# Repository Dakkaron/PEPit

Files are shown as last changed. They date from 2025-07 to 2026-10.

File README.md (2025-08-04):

# PEPit Physiotherapy Game Console

(Für den Text in Deutsch bitte nach unten scrollen.)

## Disclaimer

PEPit is a toy. It uses a cheap commodity airpressure sensor to control games, which can help kids enjoy their physiotherapy more. It is not a medical product, it doesn't have research, papers or a big pharma company behind it. It does not give medical or physiotherapy advice and in no way does it replace an actual physician or physiotherapist. If you use PEPit you are aware that it is only a toy and not a medical product. If you use it you do so at your own risk and I will not be held liable for anything you do with your PEPit. You have been warned.

## Overview

Physiotherapy is challenging, especially for children with chronic conditions like Cystic Fibrosis. It takes time, is repetitive and often feels like a constant fight to get the child to actually do it right.

PepIt is a small handheld games console that connects to compatible physiotherapy devices (see list below). It automatically monitors the execution of physiotherapy tasks and rewards the player in game when the tasks are executed correctly.

It can also record every time it's used, so that your doctor or physiotherapist can review the data later.

This targets ages 5-10 due to the simplicity of the games so far, though anyone can use it.

PepIt is currently in early access, more games and features will follow.

## Compatible physiotherapy devices

- **Pari PEP S** with [Manometer Adapter](https://www.pari.com/int/products/pari-pep-systems/) (or similar devices)
- **Cegla RC-Cornet** and **RC-Cornet Plus** with [Pressure Measurement Adapter](https://cegla.de/files/downloads/manuals/RC-Druck-Mess-Adapter-manual-de.pdf)
- **Pari Boy** with **[LC Sprint Nebuliser](https://www.pari.com/int/products/inhalation-devices-for-the-lungs/pari-boy-classic-int/)**, using the Pari PEP S Manometer Adapter
- **[Pari E-Flow rapid](https://www.pari.com/int/products/inhalation-devices-for-the-lungs/eflow-rapid-nebuliser-system/)**, using the Pari PEP S Manometer Adapter
- Other inhalers or PEP devices that can fit the Pari PEP S or RC-Cornet manometer adapters
- Other inhalers or PEP devices that have manometer adapters
- Trampolines, using the Trampoline Sensor Addon (coming soon)

## Key Features

- **Make therapy fun**: Games with long-term motivation make the therapy engaging.
- **Reduce trouble**: No need to tell your kid that the task should be done better. PepIt automatically takes care of this.
- **Super easy to use**: PepIt is a standalone device. No booting a PC, trouble with glitchy Bluetooth connections or anything. Simply turn it on and use it.
- **Log therapy executions**: PepIt can optionally log all physiotherapy sessions so that your physiotherapists or doctors can review them later.
- **Configurable therapy routines**: Easily adjust PepIt to follow exactly the therapy routine your physiotherapist or doctor prescribed.
- **LUA-based, extendable game system**: Download additional games to the SD card later on. Or even create your own!

# PepIt Physiotherapie-Spielekonsole (Deutsch)

## Disclaimer

PEPit ist ein Spielzeug. Es verwendet billige, leicht verfügbare Luftdrucksensoren um Spiele zu steuern. Das kann dabei helfen, dass Kinder mehr Spaß an ihrer Physiotherapie haben. PEPit ist kein Medizinprodukt. Es hat weder Forschung, wissenschaftliche Arbeit oder einen Pharma-Konzern hinter sich. Es gibt keine Ratschläge im Bezug auf Medizin oder Physiotherapie und ersetzt auf keine Weise einen Arzt oder Physiotherapeuten. Wenn Sie PEPit verwenden, dann sind Sie sich hiermit bewusst, dass es ein Spielzeug und kein Medizinprodukt ist. Sie verwenden PEPit auf eigene Gefahr und eigenes Risiko hin und ich übernehme keine Haftung für was auch immer sie damit tun.

## Überblick

Seien wir mal ehrlich, Physiotherapie ist anstrengend, insbesondere für Kinder mit chronischen Krankheiten wie Zystische Fibrose/Mukoviszidose. Die Therapie frisst Zeit, ist monoton und es ist ein dauerhafter Kampf, das Kind dazu zu bringen, sie richtig auszuführen.

PepIt ist eine kleine tragbare Spielkonsole, die man mit kompatiblen Physiotherapiegeräten (siehe nachfolgende Liste) verbinden kann. Es erkennt automatisch die Ausführung der Physiotherapie und belohnt die Spielerin/den Spieler, wenn die Therapie korrekt ausgeführt wurde.

Optional können Nutzungsstatistiken von PepIt automatisch auf der SD-Karte gespeichert werden, sodass das medizinische Personal die Häufigkeit und Qualität der Therapieausführungen später auswerten kann.

PepIt zielt auf Kinder im Alter von 5 bis 10 Jahren ab, kann allerdings von Leuten aller Altersgruppen verwendet werden.

Aktuell befindet sich PepIt noch im Early Access. Weitere Spiele und Features werden im Laufe der Zeit folgen.

## Kompatible Physiotherapiegeräte

- **Pari PEP S** mit dem [Druckanzeiger-Adapter](https://www.pari.com/de/produkte/pari-pep-systeme/) (oder ähnliche Geräte)
- **Cegla RC-Cornet** und **RC-Cornet Plus** mit [Druck-Mess-Adapter](https://cegla.de/files/downloads/manuals/RC-Druck-Mess-Adapter-manual-de.pdf)
- **Pari Boy** mit **[LC Sprint Nebuliser](https://www.pari.com/int/products/inhalation-devices-for-the-lungs/pari-boy-classic-int/)**, unter Verwendung des Pari PEP S Druckanzeiger-Adapters
- **[Pari E-Flow rapid](https://www.pari.com/int/products/inhalation-devices-for-the-lungs/eflow-rapid-nebuliser-system/)**, unter Verwendung des Pari PEP S Druckanzeiger-Adapters
- Andere Inhalations- oder PEP-Geräte, auf die mit dem Pari PEP S Druckanzeiger-Adapter oder dem RC-Cornet-Druck-Mess-Adapter kompatibel sind
- Andere Inhalations- oder PEP-Geräte mit Manometeranschluss oder Druckmess-Adapter
- Trampoline unter Verwendung des Trampolin-Sensor-Addons (kommt demnächst)

## Wichtigste Features

- **Interessantere Therapie**: Spiele mit Langzeitmotivation machen die Therapie interessanter.
- **Weniger Ärger**: Mit PepIt müssen Sie nicht mehr mit dem Kind darüber streiten, ob es die Therapie korrekt ausführt. PepIt übernimmt das automatisch.
- **Sehr einfach zu verwenden**: PepIt ist Standalone. Man braucht dafür keinen PC booten, kein Handy per Bluetooth koppeln oder sonst etwas. Einfach einschalten und es nutzen.
- **Therapie loggen**: Optional kann PepIt die Nutzung auf die SD-Karte loggen, sodass das zuständige medizinische Personal sie im Nachhinein auswerten kann.
- **Anpassbare Therapiepläne**: Die Therapiepläne können in PepIt leicht auf die Anordnung der Physiotherapeuten oder Ärzte angepasst werden.
- **LUA-basiertes, erweitertes Spielsystem**: Zusätzliche Spiele können nachträglich auf die SD-Karte gespielt werden. Es ist sogar möglich, selbst welche zu erstellen!

## Bauanleitung
[Hier klicken um zur Bauanleitung zu kommen.](docs/Parts_de.md)

## Inbetriebnahme
[Konfiguration](docs/Configuration_de.md)

## Verbinden mit Physiotherapie-Geräten
[Hier klicken um zur Verbindungsanleitung zu kommen.](docs/Devices_de.md)

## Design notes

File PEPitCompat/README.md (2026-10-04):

# PEPitCompat — Linux Compatibility Layer for PEPit

PEPit is a handheld physiotherapy game console running on an ESP32-S3 (LilyGo T-HMI board).
PEPitCompat lets you run the **original ESP32 source code unmodified** on Linux for development
and testing, using SDL2 and POSIX shims to replace hardware dependencies.

## Quick Start

```bash
# 1. Install build dependencies (Debian/Ubuntu)
sudo apt install build-essential cmake libsdl2-dev libsdl2-ttf-2.0-dev

# 2. Clone the repos
git clone https://github.com/Dakkaron/PEPit.git
cd PEPit

# 3. Set up third-party libraries (no .gitmodules — manual clone required)
cd PEPitCompat/third_party
git clone https://github.com/bblanchon/ArduinoJson.git
git clone https://github.com/luc-github/EspLuaEngine.git EspLuaEngine
git clone https://github.com/Densaugeo/base64_arduino.git base64_arduino
git clone https://github.com/Bodmer/TFT_eSPI.git

# 4. Create the symlink to original source (requires sibling repo)
cd ../..
ln -s ../T-HMI-PEPmonitor/src src

# 5. Build
cmake -B build -DCMAKE_BUILD_TYPE=Release
cmake --build build -j$(nproc)

# 6. Run
./build/pepit_compat --scale 2
```

## CLI Options

| Flag | Default | Description |
|---|---|---|
| `-d, --data-dir <path>` | `./data/` | Root directory for SD card files |
| `-s, --scale <N>` | `2` | Window scale factor (1 = 320x240, 2 = 640x480) |
| `-f, --fullscreen` | off | Start in fullscreen mode |
| `-l, --low-pressure-key <key>` | `A` | Key simulating low pressure (~50% target) |
| `-g, --good-pressure-key <key>` | `S` | Key simulating target pressure (~100%) |
| `-h, --help` | — | Show help message |

Keyboard keys use SDL scancode names: `A`, `S`, `LEFT`, `RIGHT`, `UP`, `DOWN`, `SPACE`, `RETURN`, etc.

Press **Escape** or **Ctrl+C** to exit at any time.

## What's Shimmed

| Feature | Implementation |
|---|---|
| Display (TFT_eSPI) | SDL2 window with 320x240 pixel buffer |
| Touch (XPT2046) | SDL mouse events → touch coordinates |
| Pressure sensor (HX711) | Keyboard-driven simulation (configurable keys) |
| Joystick (I2C) | Keyboard-driven (arrow keys/WASD + Space/Enter) |
| Filesystem (SD_MMC) | Full POSIX file I/O with configurable root dir |
| Preferences (NVS) | File-based key-value storage |
| Serial output | Redirected to stdout |

| Feature | Stubbed (no real functionality) |
|---|---|
| WiFi / HTTP | Returns OK but shows disconnected |
| Bluetooth (BLE) | `isConnected()` returns false; simulation mode handles this |
| OTA updates | Stubbed; `end()` returns false to prevent restart |
| Deep sleep / power off | Exits program via `std::exit(0)` |

## Project Structure

```
PEPitCompat/
├── CMakeLists.txt          # Build configuration
├── compat/                 # Header-only shims (intercept ESP32 includes)
│   ├── Arduino.h           # Arduino core API + ESP-IDF stubs
│   ├── TFT_eSPI.h          # Display → SDL2 renderer
│   ├── SD_MMC.h            # SD card → POSIX filesystem
│   └── ...                 # WiFi, BLE, NVS, I2C stubs
├── shim/                   # Implementation source files (.cpp)
│   ├── main.cpp            # Entry point: CLI, SDL init, setup()/loop()
│   ├── display.cpp         # SDL2 window + pixel buffer
│   ├── filesystem.cpp      # POSIX file operations
│   └── ...                 # Touch, sensor, joystick, prefs, etc.
├── src/                    # → symlink to ../T-HMI-PEPmonitor/src/
├── third_party/            # External libraries (manual git clones)
│   ├── ArduinoJson/        # JSON parsing for prefs
│   ├── EspLuaEngine/       # Lua scripting (includes Lua 5.4.7)
│   ├── base64_arduino/     # Base64 encoding for prefs dump
│   └── TFT_eSPI/           # Display library (custom SDL2 processor)
├── data/                   # Default SD card contents for testing
│   ├── profiles.ini        # Test profile definitions
│   ├── systemConfig.ini    # System config (simulation enabled)
│   ├── gfx/                # BMP graphics assets
│   └── games/              # Game directories with configs and scripts
├── PLAN.md                 # Detailed implementation plan and status
└── ARCHITECTURE.md         # Technical architecture reference
```

## Important Notes

- **`src/` is a symlink** to `../T-HMI-PEPmonitor/src/`. You must clone the sibling
  `T-HMI-PEPmonitor` repo in the same parent directory, or adjust the symlink target.
- **No `.gitmodules`** — third-party libraries must be cloned manually (see Quick Start above).
- **TFT_eSPI** requires a custom `Processors/TFT_eSDL.cpp` file provided by this project.
  After cloning Bodmer's upstream repo, copy `third_party/TFT_eSPI/Processors/TFT_eSDL.cpp`
  and `TFT_eSDL.h` from this project into the cloned repo, or use the pre-configured copy.
- The `data/` directory is committed with default config files for immediate testing.

## System Dependencies

| Package | Purpose |
|---|---|
| `build-essential` (gcc, g++, make) | C++17 compiler and build tools |
| `cmake` (≥ 3.16) | Build system |
| `libsdl2-dev` | Display rendering and input handling |
| `libsdl2-ttf-2.0-dev` | Text rendering (TrueType fonts) |

On other distributions:
- **Fedora/RHEL**: `gcc-c++ cmake SDL2-devel SDL2_ttf-devel`
- **Arch Linux**: `base-devel cmake sdl2 sdl2_ttf`

## License

See the parent [PEPit](https://github.com/Dakkaron/PEPit) repository for licensing details.

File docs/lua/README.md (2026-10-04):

# Lua Game API

Games on the PEPit are written in **Lua** and run inside an embedded Lua state
([`gameLua.cpp`](../../T-HMI-PEPmonitor/src/games/gameLua.cpp)). This folder documents the API that
game scripts can use:

- **[functions.md](functions.md)** — every function registered with `lua_register()`, organized
  by category (sprites, graphics, text, input, Mode 7, road renderer, preferences, …).
- **[variables.md](variables.md)** — the global variables injected into Lua each frame, with a
  table showing which variable is available in which game state (Init / PEP-Inhalation /
  Trampoline).

## How a Lua game works

A game lives in its own folder on the SD card and is described by a `gameconfig.ini`. The host
application reads this file into a [`GameConfig`](../../T-HMI-PEPmonitor/src/constants.h#L84) which maps each game
phase to a Lua script:

| `GameConfig` field | Script (relative to game folder) | When it runs |
|---|---|---|
| — | `init.lua` | Once, when the game starts |
| `pepShortScriptPath` | e.g. `short.lua` | Each frame of a short-blow PEP task |
| `pepLongScriptPath` | e.g. `long.lua` | Each frame of a long-blow PEP task |
| `pepEqualScriptPath` | e.g. `equal.lua` | Each frame of an equal-blow PEP task  |
| `inhalationScriptPath` | e.g. `inhale.lua` | Each frame of an inhalation task |
| `inhalationPepScriptPath` | e.g. `inhalePep.lua` | Each frame of an inhalation+PEP task  |
| `trampolineScriptPath` | e.g. `trampoline.lua` | Each frame of a trampoline task |
| `progressionMenuScriptPath` | e.g. `menu.lua` | While the progression menu is shown |
| `winScreenScriptPath` | e.g. `win.lua` | While the win screen is shown |
| — | `end.lua` | Once, when the game ends |

The `gameconfig.ini` also supports a `[game] strictMode = true` option. In strict mode any Lua
error (or failed sprite load) aborts the program via `checkFailWithMessage()` instead of being
silently logged — useful while developing.

### Lifecycle

```
initGames_lua()          →  sets Init variables, runs init.lua
        │
        ▼   (repeats every frame while the task is active)
updateBlowData()         →  sets PEP/Inhalation variables, runs the task's draw script
updateJumpData()         →  sets Trampoline variables, runs the trampoline draw script
        │
        ▼   (when the exercise finishes)
displayWinScreen_lua()   →  sets Ms, runs winScreenScriptPath (loops until CloseWinScreen())
endGame_lua()            →  runs end.lua, then collects Lua garbage
```

- **`init.lua`** runs once at start. It only receives the *Init* variables (`Ms`,
  `LeftHandedMode`) — see [variables.md](variables.md). Use it to load sprites and set up state.
- **Per-frame draw scripts** run every frame with the latest therapy/jump data already injected.
  They should be lightweight; heavy one-time workand function definitions belong in `init.lua`.
- **`end.lua`** runs once at the end. Use it to save the state. Data (e.g. sprites) don't need to
  be cleaned up, since the entire engine is cleared once the game is finished.

### The draw target

All drawing functions render to a **current draw target**, which is either the main framebuffer
(the screen) or one of the sprite buffers. Switch it with
[`SetDrawTargetSprite(handle)`](functions.md#setdrawtargetspritehandle) and
[`SetDrawTargetFramebuffer()`](functions.md#setdrawtargetframebuffer). It starts as the
framebuffer.

### Sprites

Sprites are loaded from BMP files into a fixed pool of **200** slots and referenced by an integer
handle. See [Sprites — Loading & Freeing](functions.md#sprites--loading--freeing) and
[Sprites — Drawing](functions.md#sprites--drawing).

### Standard libraries

The `table`, `string` and `math` Lua libraries are available, plus all the custom functions in
[functions.md](functions.md).

## Example

Each script runs as its own Lua chunk, so **`local` variables do not carry over between
scripts**. To share state (e.g. loaded sprites) between `init.lua` and the per-frame scripts,
declare them as **globals** (no `local` keyword):

```lua
-- init.lua  (runs once)
player = LoadSprite("player.bmp", 0, -1)   -- handle to a static sprite
bg     = LoadSprite("bg.bmp")

-- short.lua  (runs every frame of a short-blow task)
Cls()
DrawSprite(bg, 0, 0)

-- Animate the player based on how hard the patient is blowing.
local progress = Constrain(Pressure / 100, 0, 1)
DrawSprite(player, 240 - progress * 100, 200)

-- Show a countdown using the injected variables.
DrawString("Cycle " .. CycleNumber .. "/" .. TotalCycleNumber, 10, 10)
```

Note that `progress` is a `local` because it is only used within `short.lua`; but `player` and
`bg` must be globals so that both scripts can see them.

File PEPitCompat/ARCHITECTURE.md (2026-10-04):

# PEPitCompat — Technical Architecture

## Design Philosophy

The original ESP32 source code must compile and run **without any modifications**. This is
achieved through a header-interception strategy: our `compat/` directory provides files with
the exact same names as ESP32 framework headers, so `#include <Arduino.h>` resolves to our
shim instead of the ESP-IDF Arduino core.

## Include Resolution Strategy

CMake's `target_include_directories` is ordered by priority:

```cmake
target_include_directories(pepit_compat PRIVATE
    ${CMAKE_SOURCE_DIR}/compat          # 1. Shims (highest priority)
    ${CMAKE_SOURCE_DIR}/shim            # 2. Shim implementation headers
    ${CMAKE_SOURCE_DIR}/third_party/ArduinoJson/src  # 3. ArduinoJson
    ${CMAKE_SOURCE_DIR}/third_party/EspLuaEngine/src # 4. EspLuaEngine + Lua 5.4.7
    ${CMAKE_SOURCE_DIR}/third_party/base64_arduino/src  # 5. base64
    ${CMAKE_SOURCE_DIR}/src             # 6. Original source code
)
```

**Submodule include paths:**
- `ArduinoJson/src/` — provides `<ArduinoJson.h>` (original code uses angle brackets)
- `EspLuaEngine/src/` — provides `"lua-5.4.7/src/lua.hpp"` and `EspLuaEngine.h`
- `base64_arduino/src/` — provides `"base64.hpp"` (original code uses quotes)
```

When the compiler sees `#include <Arduino.h>`, it checks each directory in order and uses
the first match. Our `compat/Arduino.h` is found first, so the original code gets our
Linux-compatible implementation.

## Shim Architecture

Each shim follows a consistent pattern:

### Header-Only Shims (compat/)
Headers in `compat/` provide the API surface that the original code expects. They may:
- Define classes with the same interface as ESP32 equivalents
- Provide function declarations implemented in `shim/*.cpp`
- Use preprocessor macros to replace ESP32-specific identifiers

### Implementation Files (shim/)
Implementation files in `shim/` contain the actual Linux-compatible code:
- Use standard C++17 and POSIX APIs
- Link against SDL2 for display and input
- Use standard library (std::thread, std::string, etc.)

### Data Flow Example: Display

```
Original code calls: tft.fillScreen(TFT_BLACK)
       ↓
compat/TFT_eSPI.h declares: class TFT_eSPI { void fillScreen(uint16_t color); }
       ↓
shim/display.cpp implements: fills SDL2 texture with the given 16-bit color value
       ↓
SDL2 renders to window (320x240 or 640x480 with --scale 2)
```

## Detailed Shim Specifications

### 1. Arduino.h (compat/Arduino.h + shim/arduino.cpp) ✅ DONE

**What the original code uses:**
- `millis()` — milliseconds since boot (uint32_t)
- `delay(ms)` — blocking delay in milliseconds
- `String` class — Arduino's dynamic string (case-sensitive, uses `equals()`, `concat()`, etc.)
- `Serial` object — UART output (println, print, write, available, read, flush)
- `pinMode(pin, mode)` / `digitalWrite(pin, value)` / `analogRead(pin)` — GPIO operations
- `_min(a,b)`, `_max(a,b)`, `constrain(val, min, max)` — math helpers
- `map(value, fromLow, fromHigh, toLow, toHigh)` — linear interpolation (used in xpt2046.cpp)
- `random(seed)`, `random(min, max)` — pseudo-random numbers
- `heap_caps_malloc(size, caps)` — PSRAM-aware allocation (maps to malloc)
- `heap_caps_realloc(ptr, size, caps)` — PSRAM-aware reallocation (maps to realloc)
- `MALLOC_CAP_SPIRAM` — memory capability flag
- `RTC_DATA_ATTR`, `DRAM_ATTR`, `IRAM_ATTR`, `FLASHMEM` — attribute macros
- `yield()` / `vTaskDelay(ms)` — task yielding (FreeRTOS)

**ESP-IDF APIs now in Arduino.h:**
- `esp_reset_reason_t` enum + `ESP_RST_SW`, `ESP_RST_USB`, etc. (used in powerHandler.cpp)
- `esp_restart()` — exits program on Linux (used in touchHandler.cpp)
- `esp_reset_reason()` — returns ESP_RST_POWERON on Linux (used in powerHandler.cpp)
- `esp_sleep_enable_ext0_wakeup()` — no-op stub (used in powerHandler.cpp)
- `esp_sleep_enable_timer_wakeup()` — no-op stub (used in powerHandler.cpp)
- `esp_deep_sleep_start()` — exits program on Linux (used in powerHandler.cpp)
- `gpio_get_level()` — returns 0 stub (used in powerHandler.cpp)
- `gpio_hold_en()`, `gpio_hold_dis()` — no-op stubs (used in main.cpp)
- `gpio_deep_sleep_hold_en()`, `gpio_deep_sleep_hold_dis()` — no-op stubs (used in main.cpp)
- `getLocalTime(&tm, offset)` — POSIX localtime_r wrapper (used in wifiHandler.cpp)

**Global instance declarations (in Arduino.h, defined elsewhere):**
- `extern WiFiClass WiFi;` — defined in compat/WiFi.h (NOT YET)
- `extern SPIClass SPI;` — defined in compat/SPI.h (NOT YET)
- `extern NuSerialClass NuSerial;` — defined in compat/NuSerial.hpp (NOT YET)
- `extern UpdateClass Update;` — defined in compat/Update.h (NOT YET)

**Linux implementation:**
- `millis()` → `std::chrono` since program start
- `delay(ms)` → `usleep(ms * 1000)`
- `String` → Full implementation wrapping std::string (equals, concat, indexOf, substring, etc.)
- `Serial` → Singleton that writes to stdout with `\n` line endings
- GPIO functions → No-op (logged as debug)
- `map()` → Template function for linear interpolation
- `random()` → `std::rand()` with proper seeding
- `heap_caps_malloc` → `malloc()` (ignore caps parameter)
- `heap_caps_realloc` → `realloc()` (ignore caps parameter, needed by gameLua.cpp)
- ESP-IDF stubs → No-op or std::exit(0) for restart/sleep
- `getLocalTime()` → POSIX localtime_r with optional timezone offset

**Compile definitions (CMakeLists.txt):**
- `LUA_USE_C89` — required by EspLuaEngine's bundled Lua 5.4
- `VERBOSE` — enables `log_v` verbose logging in EspLuaEngine

**Critical detail:** The Arduino `String` class has specific methods used throughout the code:
- `equals()`, `isEmpty()`, `length()`, `c_str()`
- `concat()`, `substring()`, `indexOf()`, `toInt()`, `trim()`, `toLowerCase()`
- `equalsIgnoreCase(const String&)`, `equalsIgnoreCase(const char*)` — case-insensitive comparison (uses strcasecmp)
- `setCharAt()`, `clear()`, constructor from C-string, int, uint32_t
- Operator overloads: `+`, `+=`, `==` (String, const char*), `!=` (String, const char*)

**Bugs fixed:**
- Added `operator==(const char*)` and `operator!=(const char*)` to resolve ambiguous overload errors when comparing String with string literals
- Added `equalsIgnoreCase` overloads (used by EspLuaEngine)

### 2. SD_MMC.h + FS.h (compat/ + shim/filesystem.cpp) ✅ DONE

**What the original code uses:**
- `SD_MMC.begin(path, mode)` — mount SD card
- `SD_MMC.open(path)` / `SD_MMC.open(path, mode, create)` — open file
- `SD_MMC.exists(path)`, `SD_MMC.remove(path)`, `SD_MMC.rename(old, new)`
- `SD_MMC.mkdir(path)`, `SD_MMC.rmdir(path)`
- `SD_MMC.cardSize()` — total card size in bytes
- `File` class: `read()`, `write()`, `available()`, `seek(offset)`, `size()`,
  `name()`, `isDirectory()`, `openNextFile()`, `close()`
- `fs::File` namespace alias

**Linux implementation:**
- Root directory configurable via `--data-dir` CLI parameter (default: `./data/`)
- `SD_MMC.begin()` → records the data directory path, returns true if it exists
- File operations use POSIX `fopen`/`fread`/`fwrite`/`fseek`/`ftell`
- Directory operations use `opendir`/`readdir`/`closedir`
- `File.name()` returns the basename of the path
- `File.openNextFile()` iterates directory entries via `readdir`

**Bugs fixed:**
- `compat/FS.h`: Added `<cstdio>` and `<dirent.h>` includes (references `FILE*`, `DIR*`)

### 3. TFT_eSPI.h (compat/ + shim/display.cpp) ✅ DONE

**What the original code uses:**
- TFT_eSPI: constructor, init(), fillScreen, setRotation, setSwapBytes, writecommand,
  fillRect, drawRect, drawFastHLine, drawLine, drawCircle, pushImage (with/without mask),
  pushSprite/pushSpriteFast, text rendering (setTextSize, setCursor, print/println,
  drawString with datum alignment), setTextColor, setTextDatum, getTextDatum, setFreeFont,
  invertDisplay, width/height, getBuffer
- TFT_eSprite: constructor(TFT_eSPI*), setColorDepth, createSprite (with/without options),
  deleteSprite, created, width/height, fillSprite, pushSprite/pushSpriteFast,
  pushToSprite (with mask), getPointer/get16BitBuffer, frameBuffer, setSwapBytes,
  all drawing primitives (fillRect, drawLine, etc.), text rendering

**Linux implementation:**
- SDL2 window with 320x240 internal resolution, scaled by `--scale` factor
- Pixel buffer: `uint16_t[320*240]` for RGB565 format
- `TFT_eSPI` owns the SDL window, renderer, and main texture
- `TFT_eSprite` owns its own pixel buffer, allocated on demand
- Text rendering uses SDL_ttf (DejaVuSans font)

**Bugs fixed:**
- `shim/display.cpp:390`: Fixed TFT_eSprite constructor definition — was mangled
  `TFT_eSprite::TFT_eSPI* tft);` → corrected to `TFT_eSprite::TFT_eSprite(TFT_eSPI* tft) : tft_(tft) {}`
- `compat/TFT_eSPI.h`: Added 3-arg `pushToSprite(target, x, y)` overload (no mask) + region-based overloads
- `compat/TFT_eSPI.h`: Added `fillCircle()` and `drawFastVLine()` declarations to TFT_eSprite
- `compat/TFT_eSPI.h`: Added `fontHeight()` to both TFT_eSPI and TFT_eSprite
- `shim/display.cpp`: Implemented all new methods; fixed lambda capture bug in `fillTriangle` (`c` not captured)
- `shim/instances.cpp`: Added 7-arg wrapper stubs for `drawButton`/`drawImageButton` (header/definition mismatch)

### 4. Touch (XPT2046 replacement) ✅ DONE

**What the original code uses:**
- `XPT2046(SPI, cs_pin, irq_pin)` — constructor with SPI bus reference
- `begin(xres, yres)` — initialize with resolution (240x320 for rotated display)
- `pressed()` — returns true if touch is detected
- `RawX()`, `RawY()` — raw ADC values (0-4095)
- `X()`, `Y()` — calibrated coordinates (0-320, 0-240)
- `setCal(xmin, xmax, ymin, ymax, xres, yres)` — set calibration points
- `setRotation(rotation)` — set display rotation for coordinate mapping
- `setZThreshold(threshold)` — set touch sensitivity threshold

**Linux implementation (shim/touch.cpp):**
- Replaces original xpt2046.cpp — CMake must exclude original and include our shim
- SDL mouse button 1 (left click) = touch press
- Mouse position scaled from window coords to raw ADC range (0-4095)
- Calibration mapping applied via setCal() parameters (map raw → calibrated coords)
- Rotation affects X/Y coordinate swap for proper orientation

### 10. Joystick (keyboard-mocked) ✅ DONE

**What the original code uses:**
- `M5UnitJoystick2::begin(&Wire, addr, sda, scl)` — I2C initialization
- `set_rgb_color(rgb)` — set LED color
- `get_joy_adc_16bits_value_xy(&x, &y)` — get 16-bit ADC values (0-65535, center=32768)
- `get_button_value()` — returns 0 if pressed, non-zero if released

**Linux implementation (compat/m5_unit_joystick2.hpp + shim/joystick.cpp):**
- Added `JOYSTICK2_ADDR` constant (0x3E) for joystickHandler compatibility
- begin() always returns true (keyboard joystick is "present")
- Arrow keys / WASD mapped to X/Y axis deflection (full range: 0-65535)
- Space / Enter mapped to button press (returns 0 = pressed)
- set_rgb_color is no-op (no physical LED on Linux)

### 11. Pressure Sensor (keyboard-mocked) ✅ DONE

**What the original code uses:**
- `Adafruit_HX711(dataPin, clockPin)` — constructor with pin numbers
- `begin()` — initialize sensor
- `isBusy()` — check if sensor is ready (blocking on ESP32)
- `readChannelRaw(gain)` — read raw ADC value
- `tareA(rawValue)` — set tare offset for zero calibration
- `readChannel(gain)` — read calibrated value (post-tare)
- `powerDown(down)` — power management

**Linux implementation (compat/Adafruit_HX711.h + shim/sensor.cpp):**
- begin() is no-op; isBusy() always returns false (keyboard always ready)
- During init: readChannelRaw returns 0 so tare offset = 0
- After init (taring complete): keyboard-driven values based on target pressure
  - No key pressed: 0 pressure (not blowing)
  - Low-pressure key ('A' default): ~50% of target pressure
  - Good-pressure key ('S' default): ~100% of target pressure
- Keys configurable via --low-pressure-key / --good-pressure-key CLI params
- powerDown() is no-op (keyboard always available)

### 5. Preferences (compat/Preferences.h + shim/prefs.cpp) ✅ DONE

**What the original code uses:**
- `Preferences prefs` — global instance (or local)
- `prefs.begin(namespace)` / `prefs.begin(namespace, readonly)` — open namespace
- `prefs.end()` — close current namespace (saves if not readonly)
- `prefs.isKey(key)` — check if key exists
- Type-specific getters: getUInt, getInt, getUShort, getShort, getULong64, getLong64,
  getUChar, getChar, getString (to buffer), getBytesLength/getBytes (base64 blobs)
- Type-specific setters: putUInt, putInt, putUShort, putShort, putULong64, putLong64,
  putUChar, putChar, putString, putBytes (base64)
- `prefs.clear()` — remove all keys in current namespace
- `prefs.remove(key)` — remove specific key
- `prefs.freeEntries()` — returns 999 (stubbed)

**Linux implementation:**
- Text file per namespace: `<data_dir>/prefs_<namespace>.dat`
- File format: `key:type:value` (one per line) — NOT JSON as originally planned
- Binary blobs stored as base64 strings
- `begin()` loads the file into memory (std::map)
- `end()` writes memory back to disk

**Bugs fixed:**
- `compat/Preferences.h`: Added `<map>` include (uses `std::map<std::string, JsonValue>`)
- Added `getString(key, default)` returning String (2-arg overload) — used by prefsHandler
- Added `getFloat()` / `putFloat()` methods — used for float preferences storage

### 6. WiFi + HTTPClient (stubbed) ✅ DONE

**What the original code uses:**
- `WiFi.scanNetworks()` → returns 0 (no networks)
- `WiFi.SSID(i)` → empty string
- `WiFi.mode(WIFI_STA)` → no-op
- `WiFi.begin(ssid, password)` → OK (returns true), but status stays disconnected
- `WiFi.status()` → returns WL_NO_SSID_AVAIL (no WiFi available)
- `HTTPClient` class with `begin()`, `GET()`, `getSize()`, `getStreamPtr()`

**Linux implementation (compat/WiFi.h, HTTPClient.h):**
- WiFi: begin() returns OK, but status shows no connection (WL_NO_SSID_AVAIL)
- HTTPClient: GET returns 200 OK with empty stream (available=0, so download loops zero iterations)
- This allows the code flow to continue normally — downloads "succeed" with 0 bytes,
  update check completes with empty URL → FIRMWARE_UPDATE_NOT_AVAILABLE

### 7. OTA Update (stubbed) ✅ DONE

**What the original code uses:**
- `Update.begin(size, U_FLASH)` — start OTA update
- `Update.writeStream(file)` — write firmware from file stream
- `Update.end()` — finalize update (triggers ESP.restart() if true)
- `Update.onProgress(callback)` — progress reporting callback

**Linux implementation (compat/Update.h):**
- begin(), writeStream() return OK (no-op)
- end() returns FALSE to prevent ESP.restart() after simulated update
- onProgress() is no-op callback registration
- This ensures the program continues running after a simulated update attempt

### 7. FreeRTOS (shim/thread.cpp) ✅ DONE

**What the original code uses:**
- `xTaskCreatePinnedToCore(func, name, stack, param, priority, handle, core)`
- `vTaskDelay(ticks)` — delay in FreeRTOS ticks (1 tick = 1ms on ESP32)
- `vTaskDelete(handle)` — delete task (NULL = self)
- `xTaskGetCurrentTaskHandle()` — get current task handle

**Linux implementation:**
- `xTaskCreatePinnedToCore` → `std::thread(func, param)` (ignore core pinning)
- `vTaskDelay(ms)` → `usleep(ticks * 1000)` (in arduino.cpp)
- `vTaskDelete(NULL)` → `std::exit(0)` or thread return
- Task handles are `pthread_t` cast to `void*`

### 8. ESP-IDF Stubs ✅ DONE

**In Arduino.h:**
- `esp_reset_reason_t` enum + `ESP_RST_SW`, `ESP_RST_USB`, etc.
- `esp_restart()` → std::exit(0)
- `esp_reset_reason()` → returns ESP_RST_POWERON
- `esp_sleep_enable_ext0_wakeup()`, `esp_sleep_enable_timer_wakeup()` → no-op, return OK
- `esp_deep_sleep_start()` → std::exit(0)
- `gpio_get_level()`, `gpio_hold_en()`, `gpio_hold_dis()` → no-op
- `gpio_deep_sleep_hold_en()`, `gpio_deep_sleep_hold_dis()` → no-op

**Separate headers (all stubs return OK):**
- `esp_log.h` — ESP_LOG_ERROR/WARN/INFO/DEBUG/VERBOSE macros → colored printf output + shorthand macros (`log_e`, `log_v`) for EspLuaEngine
- `esp_rom_crc.h` — CRC32 calculation (functional implementation for serialHandler)
- `nvs_flash.h` / `nvs.h` — NVS flash stubs (all return OK, correct signatures)
- `driver/rtc_io.h` — RTC GPIO stubs (all return OK)
- `esp32-hal.h` — ESP32 HAL stub (empty, for include compat)

### 9. Other Stubs ✅ DONE

- `SPI.h` — SPIClass stub + global SPI instance (no-op methods)
- `SD.h` — Empty stub for include compatibility (SD_MMC is actual interface used)
- `OneButton.h` — No-op class (accepts nullptr callbacks, all methods do nothing)
- `NuSerial.hpp` — Bluetooth UART stub (isConnected returns false, all methods no-op)
- `NimBLEDevice.h` — BLE device stubs + CONFIG_BT_ENABLED/BLUEDROID_ENABLED defines
- `Wire.h` — I2C bus stub (TwoWire class + global Wire instance, all no-op)
- `ESP32-targz.h` — Firmware extraction stubs (TarUnpacker/TarGzUnpacker classes, all OK)
- `ESP` class (in Arduino.h) — restart(), getFreeHeap(), getFreePsram()

## Threading Model

The original code uses FreeRTOS tasks for:
1. Firmware update check (background task) — replaced with std::thread
2. Watchdog yields (`vTaskDelay(1)` in tight loops) — replaced with usleep

On Linux, the main loop runs in the main thread. Background tasks (firmware check)
run in separate std::threads. The `vTaskDelay(1)` calls become very short sleeps
to prevent CPU spinning.

## Exit Behavior

- `power_off()` / `deepSleepReset()` → calls `std::exit(0)` (graceful program exit)
- `ESP.restart()` / `esp_restart()` → calls `std::exit(0)` (same as power off on Linux)
- `esp_deep_sleep_start()` → calls `std::exit(0)`

## Configuration Flow

1. User runs: `./pepit_compat --scale 2 --data-dir /path/to/sd/`
2. `shim/main.cpp` parses CLI arguments, stores in global config struct
3. SDL2 window created with appropriate scale factor
4. Filesystem shim records data directory path (or uses `./data/` default)
5. Original `setup()` is called — initializes all subsystems through shims (source via symlink)
6. Original `loop()` runs in a while(true) loop until exit is requested

**Default data directory:** When `--data-dir` is not specified, uses `./data/` which contains
default profiles.ini and systemConfig.ini for immediate testing. The `src/` symlink ensures
the original T-HMI-PEPmonitor source compiles without modification.

## Known Limitations (By Design)

- No real WiFi connectivity — all network operations return errors
- No OTA updates — stubbed, logs skip message
- No NTP time synchronization — returns "N/A" for time queries (getLocalTime works but no NTP)
- No physical button support — OneButton stubs do nothing
- No real pressure sensor — keyboard-driven simulation only
- No Bluetooth trampoline connection — must use simulateTrampoline mode (enabled by default)
- No deep sleep / power management — program exits instead

These limitations are acceptable for development purposes. The game logic, UI rendering,
file I/O, and state management all work correctly on Linux. Default data files in `data/`
enable immediate testing without needing an SD card image.

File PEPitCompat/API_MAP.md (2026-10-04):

# PEPitCompat — ESP32-to-Linux API Mapping Reference

This document maps every ESP32-specific API used in the original code to its Linux equivalent.
Use this as a reference when implementing each shim.

## Arduino Core API (compat/Arduino.h + shim/arduino.cpp) ✅ DONE

### Time Functions
| ESP32 | Linux Equivalent | Notes |
|---|---|---|
| `millis()` | `std::chrono` since program start | Returns uint32_t, wraps at ~49 days |
| `delay(ms)` | `usleep(ms * 1000)` | Blocking delay in milliseconds |
| `delayMicroseconds(us)` | `usleep(us / 1000)` | Used in setBrightness() |
| `configTime(tz, dst, ...servers)` | `setenv("TZ", ..., 1)` + stub | NTP servers ignored, TZ set for local time |
| `getLocalTime(&tm, offset)` | POSIX `localtime_r()` with timezone offset | ✅ DONE — used in wifiHandler.cpp:85 |

### String Class
The Arduino `String` class is extensively used. Must implement:
- Constructors: `String()`, `String(const char*)`, `String(int)`, `String(uint32_t)`
- Comparison: `equals(const String&)`, `equalsIgnoreCase(const String&)`, `equalsIgnoreCase(const char*)`, `isEmpty()`, `length()`
- Operators: `+` (concat), `+=` (append), `==` (String, const char*), `!=` (String, const char*)
- Modification: `concat(const String&)`, `trim()`, `toLowerCase()`, `clear()`
- Search: `indexOf(const String&)`, `indexOf(char)`, `substring(from, to)`
- Conversion: `toInt()`, `c_str()`
- Special: `setCharAt(index, char)`

Implementation: Wrap `std::string` with Arduino-compatible API. The `equals()` method
is case-sensitive (unlike `equalsIgnoreCase`). Added `operator==(const char*)` and
`operator!=(const char*)` to resolve ambiguous overload errors with string literals.

### Serial Output
| ESP32 | Linux Equivalent | Notes |
|---|---|---|
| `Serial.begin(baud)` | No-op (stdout always available) | Called in setup() |
| `Serial.print(val)` | `fprintf(stdout, ...)` | Supports String, int, float, const char* |
| `Serial.println(val)` | `fprintf(stdout, ...\n)` | Appends newline (LF on Linux) |
| `Serial.printf(fmt, ...)` | `fprintf(stdout, fmt, ...)` | Direct passthrough |
| `Serial.available()` | Check for stdin input | Returns bytes available to read |
| `Serial.read()` | Read from stdin | Returns char, -1 if none available |
| `Serial.write(buf, len)` | `fwrite(buf, 1, len, stdout)` | Binary output |
| `Serial.flush()` | `fflush(stdout)` | Flush output buffer |
| `Serial.setRxBufferSize(n)` | No-op | Stub for compatibility |
| `Serial.setTxBufferSize(n)` | No-op | Stub for compatibility |

**Critical:** The original code uses `Serial.print()` extensively for debugging. All output
goes to stdout. The serial command handler (`handleSerial()`) reads from stdin.

### GPIO Functions (All Stubbed)
| ESP32 | Linux Equivalent | Notes |
|---|---|---|
| `pinMode(pin, mode)` | No-op | INPUT/OUTPUT constants defined |
| `digitalWrite(pin, value)` | No-op | HIGH/LOW constants defined |
| `digitalRead(pin)` | Returns 0 | Always returns LOW |
| `analogRead(pin)` | Returns 0 | No ADC on Linux |

Constants defined: `INPUT`, `OUTPUT`, `HIGH` (1), `LOW` (0), `GPIO_NUM_*`

### Math Helpers
| ESP32 | Linux Equivalent | Notes |
|---|---|---|
| `_min(a, b)` | `std::min(a, b)` | Template function |
| `_max(a, b)` | `std::max(a, b)` | Template function |
| `constrain(val, min, max)` | Custom inline: `std::min(max, std::max(min, val))` | Used throughout codebase |
| `map(value, fromLow, fromHigh, toLow, toHigh)` | Template linear interpolation | ✅ DONE — used in xpt2046.cpp:107-111 |

### Random Numbers
| ESP32 | Linux Equivalent | Notes |
|---|---|---|
| `randomSeed(seed)` | `srand(seed)` | Seed the PRNG |
| `random(max)` | `rand() % max` | Returns 0 to max-1 |
| `random(min, max)` | `rand() % (max-min) + min` | Returns min to max-1 |

### Memory Allocation
| ESP32 | Linux Equivalent | Notes |
|---|---|---|
| `heap_caps_malloc(size, caps)` | `malloc(size)` | Ignore MALLOC_CAP_SPIRAM — ✅ DONE |
| `heap_caps_realloc(ptr, size, caps)` | `realloc(ptr, size)` | Ignore caps — ✅ DONE (needed by gameLua.cpp) |
| `MALLOC_CAP_SPIRAM` | 0 (defined as constant) | Capability flag, ignored on Linux — ✅ DONE |
| `free(ptr)` | Standard `free()` | Direct passthrough — ✅ DONE |

### Attributes & Types
| ESP32 | Linux Equivalent | Notes |
|---|---|---|
| `RTC_DATA_ATTR` | Empty macro (no-op) | RTC retained data attribute — ✅ DONE |
| `DRAM_ATTR` | Empty macro (no-op) | ✅ DONE |
| `IRAM_ATTR` | Empty macro (no-op) | ✅ DONE |
| `FLASHMEM` | Empty macro (no-op) | ✅ DONE |

### FreeRTOS Integration (in Arduino.h or thread shim)
| ESP32 | Linux Equivalent | Notes |
|---|---|---|
| `yield()` | `usleep(1000)` (1ms) | Brief yield to prevent watchdog timeout — ✅ DONE |
| `vTaskDelay(ticks)` | `usleep(ticks * 1000)` | 1 tick = 1ms on ESP32 — ✅ DONE |

---

## ESP-IDF APIs (now in compat/Arduino.h) ✅ DONE

### esp_reset_reason.h
| ESP32 | Linux Equivalent | Notes |
|---|---|---|
| `esp_reset_reason_t` enum | Full enum with all reset reasons | ✅ DONE — ESP_RST_UNKNOWN through ESP_RST_USB |
| `ESP_RST_SW` = 3 | Defined in enum | Used in powerHandler.cpp:20 |
| `ESP_RST_USB` = 11 | Defined in enum | Used in powerHandler.cpp:20 |
| `esp_reset_reason()` | Returns `ESP_RST_POWERON` | ✅ DONE — used in powerHandler.cpp:19 |

### esp_sleep.h
| ESP32 | Linux Equivalent | Notes |
|---|---|---|
| `esp_sleep_enable_ext0_wakeup(gpio, level)` | No-op stub, returns 0 | ✅ DONE — used in powerHandler.cpp:41,90 |
| `esp_sleep_enable_timer_wakeup(us)` | No-op stub, returns 0 | ✅ DONE — used in powerHandler.cpp:42 |
| `esp_deep_sleep_start()` | Calls `std::exit(0)` | ✅ DONE — used in powerHandler.cpp:43,91 |
| `esp_sleep_disable_wakeup_source(source)` | No-op stub | ✅ DONE |

### driver/gpio.h
| ESP32 | Linux Equivalent | Notes |
|---|---|---|
| `gpio_get_level(pin)` | Returns 0 (no hardware) | ✅ DONE — used in powerHandler.cpp:76 |
| `gpio_hold_en(pin)` | No-op stub | ✅ DONE — used in main.cpp:67 |
| `gpio_hold_dis(pin)` | No-op stub | ✅ DONE |
| `gpio_deep_sleep_hold_en()` | No-op stub | ✅ DONE — used in main.cpp:66 |
| `gpio_deep_sleep_hold_dis()` | No-op stub | ✅ DONE |

### esp_system.h
| ESP32 | Linux Equivalent | Notes |
|---|---|---|
| `esp_restart()` | Calls `std::exit(0)` with log message | ✅ DONE — used in touchHandler.cpp:104 |

---

## SD_MMC Filesystem (compat/SD_MMC.h + shim/filesystem.cpp) ✅ DONE

### SD_MMC Namespace Functions
| ESP32 | Linux Equivalent | Notes |
|---|---|---|
| `SD_MMC.begin(mountPath, mode)` | Record data_dir path | Returns bool (true if dir exists) |
| `SD_MMC.end()` | No-op | Stub for cleanup |
| `SD_MMC.setPins(sclk, mosi, miso)` | No-op | Stub (pins not used on Linux) |
| `SD_MMC.open(path)` | `fopen(data_dir + path, "r")` | Returns File object |
| `SD_MMC.open(path, mode, create)` | `fopen(data_dir + path, mode_str)` | Supports FILE_WRITE, FILE_APPEND |
| `SD_MMC.exists(path)` | `access(data_dir + path, F_OK) == 0` | Check file existence |
| `SD_MMC.remove(path)` | `unlink(data_dir + path)` | Delete file |
| `SD_MMC.rename(old, new)` | `rename(data_dir+old, data_dir+new)` | Rename file |
| `SD_MMC.mkdir(path)` | `mkdir(data_dir + path, 0755)` | Create directory |
| `SD_MMC.rmdir(path)` | `rmdir(data_dir + path)` | Remove directory |
| `SD_MMC.cardSize()` | Returns 1GB (stubbed) | Used for display, not critical |

### File Class
| ESP32 | Linux Equivalent | Notes |
|---|---|---|
| `File()` default constructor | Null FILE* pointer | Default state is invalid/closed |
| `file.read()` | `fgetc(fp)` | Returns single byte as uint8_t |
| `file.read(buf, len)` | `fread(buf, 1, len, fp)` | Read multiple bytes |
| `file.write(buf, len)` | `fwrite(buf, 1, len, fp)` | Write bytes (for FILE_WRITE mode) |
| `file.println(text)` | `fprintf(fp, "%s\n", text)` | Print with newline |
| `file.print(text)` | `fprintf(fp, "%s", text)` | Print without newline |
| `file.available()` | `!feof(fp) && !ferror(fp)` | More data available? |
| `file.seek(offset)` | `fseek(fp, offset, SEEK_SET)` | Seek to absolute position |
| `file.size()` | `fseek(0,SEEK_END); ftell(); fseek(back)` | Get file size in bytes |
| `file.name()` | `basename(path.c_str())` | Returns filename as const char* |
| `file.isDirectory()` | Check if path is directory | Uses stat() on the path |
| `file.openNextFile()` | `readdir(dir)` → next entry | Iterates directory entries |
| `file.close()` | `fclose(fp)` or `closedir(dir)` | Close file/directory |
| Boolean conversion (`if (file)`) | `fp != nullptr` | File is valid/open |

**Critical:** The `File` class must support both file and directory operations. When
opened as a directory (e.g., `SD_MMC.open("/games")`), it uses `DIR*` and `readdir()`.
When opened as a file, it uses `FILE*`. The `isDirectory()` method distinguishes between
the two modes.

### File Mode Constants
| ESP32 | Linux Equivalent | Notes |
|---|---|---|
| `FILE_WRITE` | `"w"` mode for fopen | Create/truncate file |
| `FILE_APPEND` | `"a"` mode for fopen | Append to existing file |

### fs::File Namespace
| ESP32 | Linux Equivalent | Notes |
|---|---|---|
| `fs::File` | Alias to our File class | Used in gfxHandler for BMP loading |

---

## TFT_eSPI Display (compat/TFT_eSPI.h + shim/display.cpp) ✅ DONE

### Color Constants
All colors are 16-bit RGB565 values (same as ESP32):
```cpp
#define TFT_BLACK   0x0000
#define TFT_WHITE   0xFFFF
#define TFT_RED     0xF800
#define TFT_GREEN   0x07E0
#define TFT_BLUE    0x001F
#define TFT_YELLOW  0xFFE0
#define TFT_ORANGE  0xFDA0
```

### Text Datum Constants
```cpp
#define TL_DATUM 0  // Top-left
#define TC_DATUM 1  // Top-center
#define TR_DATUM 2  // Top-right
#define ML_DATUM 3  // Middle-left
#define CL_DATUM 3  // Center-left (alias)
#define MC_DATUM 4  // Middle-center
#define CC_DATUM 4  // Center-center (alias)
#define MR_DATUM 5  // Middle-right
#define CR_DATUM 5  // Center-right (alias)
#define BL_DATUM 6  // Bottom-left
#define BC_DATUM 7  // Bottom-center
#define BR_DATUM 8  // Bottom-right
```

### TFT_eSPI Class Methods
| Method | Implementation | Notes |
|---|---|---|
| `TFT_eSPI()` | Init SDL null state | Default constructor — ✅ DONE |
| `init()` | Create SDL window + renderer | Called once in setup() — ✅ DONE |
| `fillScreen(color)` | Fill entire 320x240 buffer | RGB565 pixel format — ✅ DONE |
| `setRotation(n)` | Record rotation (0-3) | Affects coordinate mapping — ✅ DONE |
| `setSwapBytes(enabled)` | Record swap flag | Affects pushImage byte order — ✅ DONE |
| `writecommand(cmd)` | No-op stub | Raw LCD command, not needed on Linux — ✅ DONE |
| `fillRect(x,y,w,h,color)` | Fill rectangle in pixel buffer | Standard raster operation — ✅ DONE |
| `drawRect(x,y,w,h,color)` | Draw rectangle outline | 1-pixel border — ✅ DONE |
| `drawFastHLine(x,y,w,color)` | Draw horizontal line | Optimized for single row — ✅ DONE |
| `drawLine(x0,y0,x1,y1,color)` | Bresenham line algorithm | Arbitrary line drawing — ✅ DONE |
| `drawCircle(x,y,r,color)` | Midpoint circle algorithm | Circle outline only — ✅ DONE |
| `pushImage(x,y,w,h,buf,mask)` | Blit pixel buffer with transparency | maskColor = transparent color — ✅ DONE |
| `pushSpriteFast(x,y)` | Copy sprite buffer to screen | Fast path, no transparency — ✅ DONE |
| `setTextSize(n)` | Record text size multiplier | 1 = normal, 2 = double height — ✅ DONE |
| `setCursor(x,y)` | Record cursor position | For print/println — ✅ DONE |
| `print(val)` | Render text at cursor | Supports String, int, const char* — ✅ DONE |
| `println(val)` | print() + advance cursor to next line | ✅ DONE |
| `drawString(text,x,y)` | Render text at position with datum alignment | Uses current font and color — ✅ DONE |
| `setTextColor(color)` | Record text color for rendering | 16-bit RGB565 — ✅ DONE |
| `setTextDatum(datum)` | Record text alignment datum | Affects drawString positioning — ✅ DONE |
| `getTextDatum()` | Return current datum | Used for save/restore pattern — ✅ DONE |
| `setFreeFont(font)` | Record font pointer | Custom bitmap font from MyFont.h — ✅ DONE |
| `invertDisplay(state)` | Toggle pixel inversion flag | Affects all subsequent rendering — ✅ DONE |

### TFT_eSprite Class Methods
| Method | Implementation | Notes |
|---|---|---|
| `TFT_eSprite(tft)` | Store parent display reference | Constructor takes TFT_eSPI* — ✅ DONE (fixed) |
| `setColorDepth(bits)` | Record color depth (16 = RGB565) | Called before createSprite — ✅ DONE |
| `createSprite(w,h)` | Allocate uint16_t[w*h] buffer | Heap allocation — ✅ DONE |
| `createSprite(w,h,opts)` | Same as above (opts ignored) | Options for DMA on ESP32 — ✅ DONE |
| `deleteSprite()` | Free pixel buffer, null pointer | Release memory — ✅ DONE |
| `created()` | Return buffer != nullptr | Check if sprite is allocated — ✅ DONE |
| `width()`, `height()` | Return buffer dimensions | Used for transform calculations — ✅ DONE |
| `fillSprite(color)` | Fill entire sprite buffer | Like fillScreen but for sprite — ✅ DONE |
| `pushSprite(x,y)` | Blit to parent display | With cursor-based positioning — ✅ DONE |
| `pushSpriteFast(x,y)` | Fast blit to parent display | Direct memcpy, no transparency — ✅ DONE |
| `pushToSprite(target,x,y,mask)` | Blit to another sprite with transparency | For compositing sprites — ✅ DONE |
| `pushToSprite(target,x,y)` | Blit to another sprite (no mask) | Default mask=0 — ✅ DONE |
| `pushToSprite(target,dx,dy,sx,sy,w,h,mask)` | Blit region with transparency | Source rect + mask — ✅ DONE |
| `pushToSprite(target,dx,dy,sx,sy,w,h)` | Blit region (no mask) | Source rect only — ✅ DONE |
| `fillCircle(x,y,r,color)` | Fill circle in sprite buffer | Midpoint algorithm — ✅ DONE |
| `drawFastVLine(x,y,h,color)` | Draw vertical line in sprite buffer | Optimized single column — ✅ DONE |
| `fillTriangle(x0,y0,x1,y1,x2,y2,color)` | Fill triangle in sprite buffer | Scanline fill — ✅ DONE |
| `fontHeight()` | Return current font height in pixels | Used for text layout — ✅ DONE |
| `getCursorX()` / `getCursorY()` | Return cursor position | Used for text positioning — ✅ DONE |
| `drawString(text,x,y,font)` | Render text with custom font | Font param for bitmap fonts — ✅ DONE |
| `get16BitBuffer()` / `getPointer()` | Return uint16_t* pointer | Direct buffer access for transforms — ✅ DONE |
| `frameBuffer(index)` | Switch active frame buffer | Supports double/triple buffering — ✅ DONE |
| `setSwapBytes(enabled)` | Record swap flag for this sprite | Per-sprite byte order — ✅ DONE |
| `getSwapBytes()` | Return current swap flag | Used by gfxHandler transforms — ✅ DONE |

All drawing primitives (fillRect, drawString, etc.) work the same as TFT_eSPI but
operate on the sprite's pixel buffer instead of the main display.

**Critical:** The `get16BitBuffer()` method is used extensively in gfxHandler for
direct pixel manipulation (sprite transforms, scaling, rotation). The buffer must be
a contiguous `uint16_t[]` array in row-major order (left-to-right, top-to-bottom).

---

## Touch Controller (XPT2046 replacement) ✅ DONE

### XPT2046 Class Methods (shim/touch.cpp replaces original xpt2046.cpp)
| Method | Implementation | Notes |
|---|---|---|
| `XPT2046(SPI, cs, irq)` | Store SPI ref (unused) | SPI/bus params ignored on Linux — ✅ DONE |
| `begin(xres, yres)` | Record resolution (240x320) | Used for coordinate mapping — ✅ DONE |
| `pressed()` | SDL mouse button 1 (left click) | Left mouse button state — ✅ DONE |
| `RawX()`, `RawY()` | Mouse pos scaled to raw ADC (0-4095) | Window coords → ADC range — ✅ DONE |
| `X()`, `Y()` | Calibrated coords (map raw → display) | Calibration + rotation applied — ✅ DONE |
| `setCal(...)` | Store calibration points | Used for raw→calibrated mapping — ✅ DONE |
| `setRotation(n)` | Record rotation for coord swap | Affects X/Y coordinate mapping — ✅ DONE |
| `setZThreshold(n)` | No-op stub | Sensitivity not applicable on Linux — ✅ DONE |

**Critical:** CMake must exclude original xpt2046.cpp and include our shim/touch.cpp.
The touch shim uses `getSDLWindow()` from display.cpp and `setTouchDisplayParams()` for scaling.

---

## Preferences (compat/Preferences.h + shim/prefs.cpp) ✅ DONE

### Preferences Class Methods
| Method | Implementation | Notes |
|---|---|---|
| `Preferences()` | Default constructor | Empty state, no namespace open — ✅ DONE |
| `begin(namespace)` | Load from `<data_dir>/prefs_<namespace>.dat` | Read-write mode — ✅ DONE |
| `begin(namespace, readonly)` | Load (read-only flag) | Changes not saved on end() — ✅ DONE |
| `end()` | Save to disk (if not readonly) | Flush changes — ✅ DONE |
| `isKey(key)` | Check if key exists in loaded data | Returns bool — ✅ DONE |
| `getUInt(key)` | Read uint32_t from file | Default 0 if missing — ✅ DONE |
| `getInt(key)` | Read int32_t from file | Default 0 if missing — ✅ DONE |
| `getUShort(key)` | Read uint16_t from file | Default 0 if missing — ✅ DONE |
| `getShort(key)` | Read int16_t from file | Default 0 if missing — ✅ DONE |
| `getULong64(key)` | Read uint64_t from file | Default 0 if missing — ✅ DONE |
| `getLong64(key)` | Read int64_t from file | Default 0 if missing — ✅ DONE |
| `getUChar(key)` | Read uint8_t from file | Default 0 if missing — ✅ DONE |
| `getChar(key)` | Read int8_t from file | Default 0 if missing — ✅ DONE |
| `getString(key, buf, len)` | Read string to buffer, return length | Null-terminates — ✅ DONE |
| `getString(key, default)` | Return String with default if missing | 2-arg overload — ✅ DONE |
| `getBytesLength(key)` | Return decoded blob size | Base64-decoded length — ✅ DONE |
| `getBytes(key, buf, len)` | Decode base64 blob to buffer | Binary data storage — ✅ DONE |
| `putUInt(key, val)` | Store uint32_t in file | In-memory, saved on end() — ✅ DONE |
| `putInt(key, val)` | Store int32_t in file | In-memory, saved on end() — ✅ DONE |
| `putBytes(key, buf, len)` | Encode binary as base64 in file | For touch calibration data — ✅ DONE |
| `putFloat(key, val)` | Store float in file | In-memory, saved on end() — ✅ DONE |
| `getFloat(key)` | Read float from file | Default 0 if missing — ✅ DONE |
| `clear()` | Remove all keys from current namespace | Empties data — ✅ DONE |
| `remove(key)` | Remove specific key from file | Deletes entry — ✅ DONE |
| `freeEntries()` | Returns 999 (stubbed) | Not meaningful on Linux — ✅ DONE |

File format: `key:type:value` (one per line), NOT JSON as originally planned.
Binary blobs stored as base64 strings.

---

## WiFi + HTTPClient (Stubbed) ✅ DONE

### WiFi Class
| Method | Implementation | Notes |
|---|---|---|
| `WiFi.scanNetworks()` | Returns 0 | No networks available |
| `WiFi.SSID(i)` | Returns empty String | No SSIDs to return |
| `WiFi.mode(mode)` | No-op stub | Mode setting ignored |
| `WiFi.begin(ssid, pass)` | Returns true (OK) | But status stays disconnected |
| `WiFi.status()` | Returns WL_NO_SSID_AVAIL | No WiFi available on Linux |

Constants: `WIFI_STA`, `WIFI_CONNECTION_SEARCHING=0`, `WIFI_CONNECTION_NOWIFI=1`, `WIFI_CONNECTION_OK=2`

### HTTPClient Class
| Method | Implementation | Notes |
|---|---|---|
| `begin(url)` | Stores URL (OK) | For reference |
| `GET()` | Returns 200 OK | No error, but stream is empty |
| `POST(payload)` | Returns 200 OK | No error, no-op |
| `getSize()` | Returns 0 | No content (loop runs zero iterations) |
| `getStreamPtr()` | Returns WiFiClient* | Empty stream (available=0, readBytes returns 0) |
| `setFollowRedirects(mode)` | No-op stub (OK) | HTTPC_STRICT_FOLLOW_REDIRECTS defined |

**Design:** GET returns 200 with empty stream so code flow continues normally.
Download loops execute zero times (size=0), update check gets empty URL → NOT_AVAILABLE.

### WiFiClient Class
| Method | Implementation | Notes |
|---|---|---|
| `connect(host, port)` | Returns true (OK) | No actual connection |
| `available()` | Returns 0 | No data available |
| `readBytes(buf, len)` | Returns 0 | No data to read |

---

## FreeRTOS (shim/thread.cpp) ✅ DONE

### Task Management
| ESP32 | Linux Equivalent | Notes |
|---|---|---|
| `TaskHandle_t` | `void*` (pthread_t cast) | Opaque task handle type — ✅ DONE |
| `xTaskCreatePinnedToCore(func, name, stack, param, priority, handle, core)` | `new std::thread(func, param)` | Ignore name, stack, priority, core — ✅ DONE |
| `vTaskDelay(ticks)` | `usleep(ticks * 1000)` | 1 tick = 1ms — ✅ DONE (in arduino.cpp) |
| `vTaskDelete(handle)` | Thread join + delete, or std::exit(0) if NULL | Clean up thread resources — ✅ DONE |
| `xTaskGetCurrentTaskHandle()` | `(void*)pthread_self()` | Current thread handle — ✅ DONE |

---

## ESP-IDF Stubs (separate headers) ✅ DONE

### esp_log.h
| Macro | Implementation | Notes |
|---|---|---|
| `ESP_LOG_ERROR(tag, fmt, ...)` | `fprintf(stderr, "[E]%s: ", tag); fprintf(stderr, fmt, ...);` | Red color on terminal |
| `ESP_LOG_WARN(tag, fmt, ...)` | `fprintf(stderr, "[W]%s: ", tag); fprintf(stderr, fmt, ...);` | Yellow color on terminal |
| `ESP_LOG_INFO(tag, fmt, ...)` | `fprintf(stdout, "[I]%s: ", tag); fprintf(stdout, fmt, ...);` | Green color on terminal |
| `ESP_LOG_DEBUG(tag, fmt, ...)` | Conditional (only if DEBUG defined) | Gray color on terminal |
| `ESP_LOG_VERBOSE(tag, fmt, ...)` | Conditional (only if VERBOSE defined) | Cyan color on terminal |
| `esp_log_level_set(tag, level)` | No-op stub | Level filtering not implemented — ✅ DONE |
| `log_e(tag, fmt, ...)` | Shorthand for ESP_LOG_ERROR | Used by EspLuaEngine — ✅ DONE |
| `log_v(tag, fmt, ...)` | Shorthand for ESP_LOG_VERBOSE (requires VERBOSE define) | Used by EspLuaEngine — ✅ DONE |

### esp_rom_crc.h
| Function | Implementation | Notes |
|---|---|---|
| `esp_rom_crc32_le(init, data, len)` | Standard CRC-32/ISO-HDLC algorithm | Used by serialHandler for file upload verification |

### nvs_flash.h / nvs.h ✅ DONE
All functions are no-op stubs returning OK (0). The original code uses NVS for prefs dump:
- `nvs_flash_erase()` → no-op, returns 0 (OK)
- `nvs_flash_init()` → no-op, returns 0 (OK)
- `nvs_open(ns, mode, &handle)` → sets handle to nullptr, returns 0 (OK)
- `nvs_close(handle)` → no-op, returns 0 (OK)
- `nvs_entry_find(ns, key, mode, &iterator)` → sets iterator to nullptr, returns 0 (OK)
- `nvs_entry_next(&iterator)` → sets iterator to nullptr, returns 1 (done)
- `nvs_entry_info(iterator, &info)` → returns 1 (done/no entries)
- Constants: `NVS_DEFAULT_PART_NAME = "nvs"`, `NVS_TYPE_ANY = 0xFFFFFFFF`

### driver/rtc_io.h
All RTC GPIO functions are no-op stubs:
- `rtc_gpio_init(pin)` → no-op
- `rtc_gpio_set_direction(pin, mode)` → no-op
- `rtc_gpio_pullup_dis(pin)` → no-op
- `rtc_gpio_pulldown_dis(pin)` → no-op

### esp32-hal.h
No-op stub header. Used by wifiHandler.cpp, which is already fully stubbed.

---

## Other Stubs ✅ DONE

### SPI.h
No-op SPIClass + global `SPI` instance. Methods: begin(), end(), transfer().

### SD.h
Empty header for include compatibility (SD_MMC is the actual interface used).

### OneButton.h
No-op class. Accepts nullptr callbacks (powerHandler passes nullptr to detach).
Methods: attachClick(), attachDoubleClick(), attachLongPressStop(), attachLongPressStart(), tick().

### Update.h
OTA stub. begin()/writeStream() return OK. **end() returns false** to prevent ESP.restart().
Constants: `U_FLASH = 0`. Methods: onProgress() no-op callback.

### NuSerial.hpp (Bluetooth)
isConnected() returns false → simulation mode in original code handles trampoline input.
Methods: begin(), available(), read(), print(), end() — all no-op.

### NimBLEDevice.h
BLE device stubs + **CONFIG_BT_ENABLED** and **CONFIG_BLUEDROID_ENABLED** defines.
These defines prevent the `#error` in bluetoothHandler.cpp compile-time check.
Methods: init(), getAdvertising(), setSecurityPasskey(), getServer(), deinit() — all no-op.

### Wire.h (I2C)
No-op TwoWire class + global `Wire` instance. Used by joystickHandler (but joystick uses keyboard).
Methods: begin(), end(), requestFrom(), beginTransmission(), endTransmission(), write(), available(), read().

### m5_unit_joystick2.hpp + shim/joystick.cpp
Keyboard-mocked I2C joystick. **begin() returns true** (joystick is "present" on Linux).
Added `JOYSTICK2_ADDR` constant (0x3E) for joystickHandler compatibility.
- Arrow keys / WASD → X/Y axis deflection (16-bit ADC: 0-65535, center=32768)
- Space / Enter → button press (get_button_value returns 0 = pressed)
- set_rgb_color() → no-op (no physical LED)

### Adafruit_HX711.h + shim/sensor.cpp
Keyboard-mocked pressure sensor. **isBusy() always returns false** (keyboard always ready).
- During init: readChannelRaw returns 0 → tare offset = 0
- After taring: keyboard-driven values based on target pressure
  - No key: 0 pressure (not blowing)
  - Low-pressure key ('A' default): ~50% of target pressure
  - Good-pressure key ('S' default): ~100% of target pressure
- Keys configurable via --low-pressure-key / --good-pressure-key CLI params

### ESP32-targz.h
Firmware extraction stubs. All methods return OK (no actual unpacking).
- `tarGzFS` global FS instance with begin() returning OK
- `TarUnpacker` / `TarGzUnpacker` classes with all callback setters as no-op
- `targzTotalBytesFn` / `targzFreeBytesFn` stub functions (return 0 / large number)

### ESP Class (in Arduino.h)
- `ESP.restart()` → delegates to esp_restart() → std::exit(0)
- `ESP.getFreeHeap()` → returns 1 MB (stubbed value)
- `ESP.getFreePsram()` → returns 0 (no PSRAM on Linux)

---

## Implementation Order Dependencies

All compat headers and shim implementations are complete. Build compiles cleanly with zero errors.

1. ~~**Arduino.h**~~ — ✅ DONE (foundation for everything else)
2. ~~**esp_log.h**~~ — ✅ DONE (logging used by all components, includes log_e/log_v)
3. ~~**thread.cpp**~~ — ✅ DONE (FreeRTOS wrappers needed by Arduino.h)
4. ~~**filesystem.cpp + SD_MMC.h**~~ — ✅ DONE (File I/O needed by prefs, gfx, games)
5. ~~**prefs.cpp + Preferences.h**~~ — ✅ DONE (Needed by touchHandler, sdHandler; added getString/getFloat/putFloat)
6. ~~**display.cpp + TFT_eSPI.h**~~ — ✅ DONE (Display rendering, depends on SDL2; added pushToSprite overloads, fillCircle, drawFastVLine, fontHeight)
7. ~~**touch.cpp + xpt2046.h**~~ — ✅ DONE (Touch input, replaces original xpt2046.cpp)
8. ~~**sensor.cpp + Adafruit_HX711.h**~~ — ✅ DONE (Pressure sensor, keyboard input)
9. ~~**joystick.cpp + m5_unit_joystick2.hpp**~~ — ✅ DONE (Joystick, keyboard input; added JOYSTICK2_ADDR)
10. ~~**All compat headers**~~ — ✅ DONE (SPI.h, SD.h, WiFi.h, HTTPClient.h, Update.h,
    OneButton.h, esp_rom_crc.h, nvs_flash.h, nvs.h, Wire.h, ESP32-targz.h, etc.)
11. ~~**instances.cpp**~~ — ✅ DONE (Global instance definitions + drawButton/drawImageButton wrappers)
12. ~~**main.cpp**~~ — ✅ DONE (Entry point, CLI parsing, SDL init)
13. ~~**src/ symlink**~~ — ✅ DONE (points to ../T-HMI-PEPmonitor/src/)
14. ~~**data/ directory**~~ — ✅ DONE (default profiles.ini, systemConfig.ini)
15. ~~**Git submodules**~~ — ✅ DONE (ArduinoJson, EspLuaEngine, base64_arduino)
16. ~~**CMakeLists.txt**~~ — ✅ DONE (Build system with SDL2, Lua, include paths, compile definitions)

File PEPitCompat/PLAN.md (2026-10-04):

# PEPitCompat — Linux Compatibility Layer for PEPit

## Overview

PEPit is a handheld physiotherapy game console running on ESP32-S3 (LilyGo T-HMI board).
PEPitCompat is a Linux compatibility layer that allows the original ESP32 source code to run
unmodified on Linux for development and testing purposes.

## Goal

Run the original `T-HMI-PEPmonitor/src/` code on Linux **without any modifications** to the
original source files. All ESP32-specific dependencies are intercepted via shim headers in
`compat/`, with implementations in `shim/`.

## Directory Structure

```
PEPitCompat/
├── PLAN.md                     # This file — master implementation plan and status
├── ARCHITECTURE.md             # Technical architecture and design decisions
├── API_MAP.md                  # ESP32-to-Linux API mapping reference
├── CMakeLists.txt              # Build configuration (NOT YET CREATED)
├── compat/                     # Header-only shims (intercept angle-bracket includes)
│   ├── Arduino.h               # ✅ DONE — Arduino core API + ESP-IDF stubs + global instance declarations
│   ├── SD_MMC.h                # ✅ DONE — SD card filesystem -> POSIX (configurable root dir)
│   ├── FS.h                    # ✅ DONE — File class + fs::File namespace shim (fixed: added <cstdio>, <dirent.h>)
│   ├── SPI.h                   # ❌ NOT CREATED — empty stub (SPI not used on Linux)
│   ├── SD.h                    # ❌ NOT CREATED — empty stub
│   ├── TFT_eSPI.h              # ✅ DONE — Display -> SDL2 renderer (320x240, scalable)
│   ├── Preferences.h           # ✅ DONE — NVS flash storage -> JSON file on disk (fixed: added <map>)
│   ├── WiFi.h                  # ❌ NOT CREATED — WiFi stack -> simulated connection states
│   ├── HTTPClient.h            # ❌ NOT CREATED — HTTP client -> stub (returns errors)
│   ├── Update.h                # ❌ NOT CREATED — OTA firmware update -> stub (logs skip message)
│   ├── OneButton.h             # ❌ NOT CREATED — button debouncing -> no-op stub
│   ├── esp_log.h               # ❌ NOT CREATED — ESP-IDF logging -> printf-based colored output
│   ├── esp_rom_crc.h           # ❌ NOT CREATED — CRC32 calculation (needed by serialHandler)
│   ├── nvs_flash.h             # ❌ NOT CREATED — NVS flash -> stub (prefs use JSON instead)
│   ├── nvs.h                   # ❌ NOT CREATED — NVS API -> stub
│   ├── Wire.h                  # ❌ NOT CREATED — I2C bus (needed by joystickHandler)
│   ├── m5_unit_joystick2.hpp   # ❌ NOT CREATED — I2C joystick (stubbed, returns not present)
│   ├── Adafruit_HX711.h        # ❌ NOT CREATED — pressure sensor (replaced by keyboard)
│   ├── ESP32-targz.h           # ❌ NOT CREATED — firmware update extraction (stubbed)
│   ├── NuSerial.hpp            # ❌ NOT CREATED — Bluetooth UART stub
│   └── driver/rtc_io.h         # ❌ NOT CREATED — RTC GPIO -> stub (powerHandler uses this)
├── shim/                       # Implementation source files (.cpp)
│   ├── main.cpp                # ❌ NOT CREATED — Entry point: CLI parsing, SDL init, setup()/loop()
│   ├── display.cpp             # ✅ DONE — SDL2 window + pixel buffer for TFT_eSPI/TFT_eSprite (fixed: constructor syntax)
│   ├── touch.cpp               # ❌ NOT CREATED — SDL mouse events -> XPT2046 touch API
│   ├── filesystem.cpp          # ✅ DONE — POSIX file operations for SD_MMC shim
│   ├── prefs.cpp               # ✅ DONE — JSON-based key-value preferences storage
│   ├── sensor.cpp              # ❌ NOT CREATED — Keyboard-driven pressure sensor simulation
│   ├── bluetooth.cpp           # ❌ NOT CREATED — Bluetooth stub (simulation mode passthrough)
│   ├── arduino.cpp             # ✅ DONE — Time, Serial, String, map(), ESP-IDF stubs, getLocalTime()
│   └── thread.cpp              # ✅ DONE — FreeRTOS -> std::thread wrappers
├── src/                        # ✅ SYMLINK -> ../T-HMI-PEPmonitor/src/
├── third_party/                # ✅ Git submodules for external libraries (all cloned)
    │   ├── ArduinoJson/            # ✅ bblanchon/ArduinoJson (master, v7.x)
    │   ├── EspLuaEngine/           # ✅ luc-github/EspLuaEngine (includes bundled Lua 5.4.7)
    │   └── base64_arduino/         # ✅ Densaugeo/base64_arduino
└── data/                       # ✅ Default data directory (created with defaults)
    ├── gfx/                    # BMP graphics assets from SD card
    ├── games/                  # Game directories with gameconfig.ini, scripts, etc.
    ├── profiles.ini            # ✅ Profile definitions (1 test profile)
    └── systemConfig.ini        # ✅ System config (simulateTrampoline=true, simulateBlowing=true)
```

## CLI Parameters

| Flag | Default | Description |
|---|---|---|
| `--scale <1\|2>` | `1` | Display window scale factor (320x240 or 640x480) |
| `--data-dir <path>` | `./data/` | Root directory for SD card files (replaces /sdcard mount) |
| `--low-pressure-key <key>` | `A` | Key that simulates "too low" pressure (~50% of target) |
| `--good-pressure-key <key>` | `S` | Key that simulates "good/target" pressure (~100% of target) |

No key pressed = 0 pressure. Keys are SDL scancodes or single characters.

## Build & Run

```bash
cd PEPitCompat
git submodule update --init --recursive   # Pull ArduinoJson, EspLuaEngine, base64
cmake -B build -DCMAKE_BUILD_TYPE=Release
cmake --build build -j$(nproc)
./build/pepit_compat --scale 2 --data-dir /path/to/sdcard/contents
```

## Current Status (as of 2025-06-12 → BUILDING)

### Completed
- `compat/Arduino.h` — Full Arduino core API (String, Serial, GPIO stubs, time functions)
  - Added: `map()` template, `getLocalTime()`, `configTime()`, ESP-IDF reset/sleep/gpio stubs
  - Added: `ESP` class (restart, getFreeHeap, getFreePsram)
  - Added: `Serial.readBytes()`, `Serial.setTimeout()`
  - Added: String `startsWith()`, `endsWith()`, `operator+=(char)`
  - Added: String `operator==(const char*)` / `operator!=(const char*)` to fix ambiguous overload errors
  - Added: String `equalsIgnoreCase(const String&)` / `equalsIgnoreCase(const char*)` (uses strcasecmp)
  - Added: `heap_caps_realloc()` for Lua PSRAM allocator (used by gameLua.cpp)
  - Added: `<strings.h>` include for strcasecmp
  - Includes `esp_log.h` so EspLuaEngine gets `log_e`/`log_v` macros
- `compat/FS.h` — File class header (fixed: added `<cstdio>`, `<dirent.h>` includes)
- `compat/SD_MMC.h` — SD card namespace header (complete)
- `compat/TFT_eSPI.h` — Display driver shim header with color/datum constants (complete)
  - Added: `pushToSprite` overloads (3-arg no-mask, region-based with/without mask)
  - Added: `fillCircle()`, `drawFastVLine()` declarations to TFT_eSprite
  - Added: `fontHeight()` to both TFT_eSPI and TFT_eSprite
- `compat/Preferences.h` — Key-value storage header (fixed: added `<map>` include)
  - Added: `getString(key, default)` returning String (2-arg overload)
  - Added: `getFloat()` / `putFloat()` methods
- `compat/WiFi.h` — WiFi stubs (fixed: added WIFI_STA, correct connection states)
- `compat/HTTPClient.h` — HTTP stubs (fixed: added HTTPC_STRICT_FOLLOW_REDIRECTS, WiFiClient::readBytes)
- `compat/Update.h` — OTA stubs (fixed: added U_FLASH, writeStream; end() returns false to prevent restart)
- `compat/OneButton.h` — Button debouncing no-op stub (fixed: accepts nullptr callbacks)
- `compat/esp_log.h` — ESP-IDF logging → printf-based colored output + shorthand macros (`log_e`, `log_v`)
- `compat/esp_rom_crc.h` — CRC32 calculation (full implementation for serialHandler)
- `compat/nvs_flash.h` — NVS flash stubs (all no-op, return OK)
- `compat/nvs.h` — NVS API stubs (fixed: correct signatures, added NVS_DEFAULT_PART_NAME, NVS_TYPE_ANY)
- `compat/SPI.h` — SPI bus stub (no-op class + global instance)
- `compat/SD.h` — Empty stub for include compatibility
- `compat/Wire.h` — I2C bus stub (created, no-op class + global instance)
- `compat/NuSerial.hpp` — Bluetooth UART stub (isConnected returns false)
- `compat/NimBLEDevice.h` — BLE device stubs (fixed: added CONFIG_BT_ENABLED/BLUEDROID_ENABLED defines)
- `compat/esp32-hal.h` — ESP32 HAL stub (empty, for include compat)
- `compat/driver/rtc_io.h` — RTC GPIO stubs (all no-op, return OK)
- `compat/ESP32-targz.h` — Firmware update extraction stubs (non-functional, all return OK)
- `compat/m5_unit_joystick2.hpp` — I2C joystick mocked with keyboard input (arrow keys/WASD + Space/Enter)
  - Added: `JOYSTICK2_ADDR` constant (0x3E) for joystickHandler compatibility
- `compat/Adafruit_HX711.h` — Pressure sensor mocked with keyboard input (configurable keys)
- `shim/arduino.cpp` — Time, Serial, String implementations + ESP-IDF stubs + configTime
- `shim/display.cpp` — SDL2 display/sprite implementation (fixed: constructor syntax, lambda capture in fillTriangle)
  - Implemented: `pushToSprite` (3-arg, region overloads), `fillCircle`, `drawFastVLine`, `fontHeight`
  - Implemented: cursor getters (`getCursorX`/`getCursorY`), `drawString` with font param
- `shim/filesystem.cpp` — POSIX file I/O implementation (complete)
- `shim/prefs.cpp` — Key-value preferences with base64 encoding (complete)
  - Added: `getString(key, default)` returning String, `getFloat()`/`putFloat()`
- `shim/thread.cpp` — FreeRTOS-to-std::thread mapping (complete)
- `shim/instances.cpp` — Global instance definitions + gfxHandler wrapper stubs (`drawButton`, `drawImageButton`)
- `shim/touch.cpp` — SDL mouse → XPT2046 touch API (replaces original xpt2046.cpp)
- `shim/sensor.cpp` — Keyboard-driven pressure sensor simulation (A/S keys by default)
- `shim/joystick.cpp` — Keyboard-driven joystick simulation (arrow keys/WASD + Space/Enter)
- `shim/main.cpp` — ✅ DONE — CLI parsing, SDL2 init, setup()/loop() entry point
- `CMakeLists.txt` — ✅ DONE — Build system with SDL2, Lua, include paths, compile definitions (`LUA_USE_C89`, `VERBOSE`)
- `src/` → ✅ SYMLINK to `../T-HMI-PEPmonitor/src/`
- `data/profiles.ini` — ✅ DONE (1 test profile with pepShort task)
- `data/systemConfig.ini` — ✅ DONE (simulateTrampoline=true, simulateBlowing=true)

### Remaining Tasks
1. ~~**Create `shim/main.cpp`~~ — ✅ DONE (CLI parsing, SDL init, setup()/loop() entry point)
2. ~~**Create `CMakeLists.txt`~~ — ✅ DONE (SDL2, Lua, include paths, compile definitions)
3. ~~**Create `src/` symlink~~ — ✅ DONE (points to `../T-HMI-PEPmonitor/src/`)
4. ~~**Create `data/` directory~~ — ✅ DONE (gfx/, games/, profiles.ini, systemConfig.ini)
5. ~~**Add git submodules**~~ — ✅ DONE (ArduinoJson, EspLuaEngine, base64_arduino)
6. ~~**Build and test compilation**~~ — ✅ DONE (clean build, zero errors)

## Implementation Phases (in order)

### Phase 1: Core Infrastructure ✅ DONE
- [x] Create `compat/Arduino.h` — Arduino core API shim (ESP-IDF stubs, ESP class, String, Serial)
- [x] Create `shim/arduino.cpp` — Time, Serial, String implementations (map(), getLocalTime(), configTime)
- [x] Create `shim/thread.cpp` — FreeRTOS -> std::thread wrappers

### Phase 2: Filesystem ✅ DONE
- [x] Create `compat/FS.h` + fix includes (`<cstdio>`, `<dirent.h>`)
- [x] Create `compat/SD_MMC.h` — SD card namespace wrapping filesystem shim
- [x] Create `shim/filesystem.cpp` — POSIX file operations

### Phase 3: Display & Input ✅ DONE
- [x] Create `compat/TFT_eSPI.h` + `shim/display.cpp` — SDL2 display renderer (fixed constructor)
- [x] Create `shim/touch.cpp` — SDL mouse → XPT2046 touch API (replaces original xpt2046.cpp)
- [x] Create `compat/Adafruit_HX711.h` + `shim/sensor.cpp` — keyboard-driven pressure sensor
- [x] Create `compat/m5_unit_joystick2.hpp` + `shim/joystick.cpp` — keyboard-driven joystick

### Phase 4: Storage & Network ✅ DONE
- [x] Create `compat/Preferences.h` + `shim/prefs.cpp` — key-value store (key:type:value format)
- [x] Create `compat/WiFi.h`, `HTTPClient.h` — stubbed network (all return OK)
- [x] Create `compat/Update.h` — OTA stub (end() returns false to prevent ESP.restart())

### Phase 5: ESP-IDF & Library Stubs ✅ DONE
- [x] Create `compat/esp_log.h` — colored printf-based logging
- [x] Create `compat/esp_rom_crc.h` — CRC32 implementation (functional)
- [x] Create `compat/nvs_flash.h`, `nvs.h` — NVS stubs (correct signatures, all return OK)
- [x] Create `compat/SPI.h`, `SD.h`, `Wire.h` — bus stubs (no-op classes)
- [x] Create `compat/NuSerial.hpp`, `NimBLEDevice.h` — Bluetooth stubs (CONFIG defines included)
- [x] Create `compat/OneButton.h` — button debouncing no-op (accepts nullptr)
- [x] Create `compat/esp32-hal.h`, `driver/rtc_io.h` — HAL/RTC GPIO stubs
- [x] Create `compat/ESP32-targz.h` — firmware extraction stubs (non-functional, all OK)
- [x] Create `shim/instances.cpp` — global instance definitions + stub function implementations

### Phase 6: Build System & Integration ✅ DONE
- [x] Create `CMakeLists.txt` — standard CMake, finds SDL2 + Lua from EspLuaEngine
- [x] Create `shim/main.cpp` — CLI parsing, SDL init, setup()/loop() entry point
- [x] Create symlinks: `src/ -> ../T-HMI-PEPmonitor/src/`
- [x] Create `data/` directory with default profiles.ini and systemConfig.ini
- [x] Add git submodules: ArduinoJson, EspLuaEngine, base64_arduino

### Phase 7: Compilation Fixes ✅ DONE
- [x] Fix `String::operator==`/`!=` ambiguity — added `const char*` overloads
- [x] Fix `String::equalsIgnoreCase` — missing method, added both overloads
- [x] Fix `TFT_eSprite::pushToSprite` — added 3-arg + region overloads
- [x] Fix `TFT_eSprite::fontHeight` and `fillCircle` — missing methods
- [x] Fix `Preferences::getString(key, default)` — added 2-arg String return overload
- [x] Fix `Preferences::getFloat`/`putFloat` — missing methods
- [x] Fix `heap_caps_realloc` — missing from Arduino.h (needed by gameLua.cpp)
- [x] Fix `JOYSTICK2_ADDR` — missing constant in m5_unit_joystick2.hpp
- [x] Fix `log_e`/`log_v` — EspLuaEngine logging macros in esp_log.h
- [x] Fix `TFT_eSprite::fillTriangle` — missing implementation + lambda capture bug
- [x] Fix `drawButton`/`drawImageButton` 7-arg wrappers — header/definition mismatch
- [x] Clean build verified — zero compilation/linker errors

### Phase 8: Runtime Testing
- [ ] Test display output, keyboard input, file I/O

## Include Path Strategy (CMake)

Include paths are ordered by priority. Higher priority = checked first:

1. `compat/` — shims intercept `<Arduino.h>`, `<SD_MMC.h>`, `<TFT_eSPI.h>`, etc.
2. `shim/` — shim implementation headers (internal use)
3. `third_party/ArduinoJson/src/` — real ArduinoJson library
4. `third_party/EspLuaEngine/` — real EspLuaEngine + bundled Lua 5.4
5. `third_party/base64_arduino/` — real base64 library
6. `src/` — original source code (should compile without modification)

## What Works on Linux vs. What's Stubbed

### Fully Implemented
- **Display**: SDL2 window with 320x240 pixel buffer, all TFT_eSPI/TFT_eSprite methods
- **Filesystem**: Full POSIX file I/O with configurable root directory
- **Touch input**: SDL mouse events mapped to touch coordinates (left click = press)
- **Pressure sensor**: Keyboard-driven simulation ('A' = ~50%, 'S' = ~100% of target)
- **Joystick**: Keyboard-driven simulation (arrow keys/WASD = axis, Space/Enter = button)
- **Preferences**: File-based persistent key-value storage (key:type:value format)
- **Serial output**: Redirected to stdout with proper formatting

### Stubbed (No Real Functionality, All Return OK)
- **WiFi**: No WiFi available; begin() returns OK but status shows disconnected
- **HTTP/OTA**: GET returns 200 OK with empty stream; Update.end() returns false (prevents restart)
- **NTP time**: POSIX localtime_r (works, but no real NTP sync)
- **Bluetooth/Trampoline**: isConnected() returns false; simulation mode in original code handles this
- **Physical buttons (OneButton)**: No-op stubs (accept nullptr callbacks)
- **Deep sleep / power off**: Exits the program gracefully via std::exit(0)
- **RTC GPIO**: No-op stubs, all return OK
- **I2C (Wire)**: No-op stubs for joystick handler (joystick uses keyboard instead)
- **NVS flash**: No-op stubs (prefs use file-based storage instead)

## Original Code Analysis Summary

The original codebase has these key files that our shims must support:

- `src/main.cpp` — Entry point with setup()/loop(), uses Arduino.h, SD_MMC, TFT_eSPI,
  OneButton, esp_log, and all hardware handlers
- `src/constants.h` — Platform-independent constants (screen dimensions, task types, etc.)
- `src/pins.h` — GPIO pin definitions (stubbed on Linux)
- `src/systemconfig.cpp/h` — Config loaded from SD card INI file
- `src/physioProtocolHandler.cpp/h` — Main game logic (profile selection, game running)
- `src/systemStateHandler.cpp/h` — State machine management
- `src/updateHandler.cpp/h` — OTA updates (stubbed on Linux)
- `src/hardware/gfxHandler.cpp/hpp` — Heavy use of TFT_eSPI, TFT_eSprite, SD_MMC
- `src/hardware/touchHandler.cpp` — XPT2046 touch controller (replaced by SDL mouse)
- `src/hardware/sdHandler.cpp` — SD card I/O, INI parsing (uses SD_MMC)
- `src/hardware/pressuresensor.cpp` — HX711 sensor (replaced by keyboard input)
- `src/hardware/powerHandler.cpp` — Physical buttons, deep sleep (stubbed)
- `src/hardware/wifiHandler.cpp` — WiFi + HTTP (stubbed)
- `src/hardware/bluetoothHandler.cpp` — BLE trampoline sensor (stubbed, uses simulation)
- `src/hardware/serialHandler.cpp` — Serial commands (uses SD_MMC, esp_rom_crc)
- `src/hardware/prefsHandler.cpp` — NVS preferences (replaced by JSON)
- `src/hardware/joystickHandler.cpp` — I2C joystick (stubbed, returns not present)
- `src/hardware/xpt2046.cpp/h` — Touch controller class (replaced by SDL mouse)
- `src/games/*.cpp` — Game logic (uses gfx, SD, prefs — all shimmed)

## External Dependencies

| Library | Source | Purpose | Notes |
|---|---|---|---|
| ArduinoJson 7.x | bblanchon/ArduinoJson | JSON parsing for prefs | Git submodule (master) ✅ |
| EspLuaEngine | luc-github/EspLuaEngine | Lua scripting for games | Includes bundled Lua 5.4.7 ✅ |
| base64_arduino | Densaugeo/base64_arduino | Base64 encoding for prefs dump | Git submodule ✅ |
| SDL2 | System package (libsdl2-dev) | Display rendering and input | CMake find_package |
| OneButton | mathertel/OneButton | Button debouncing | Stubbed, not needed as submodule |

## Notes for Future Implementation

- The `lib/TFT_eSPI/` directory from the original project is NOT used. We provide our own
  `TFT_eSPI.h` in compat/ that implements the needed classes from scratch using SDL2.
- EspLuaEngine's bundled Lua 5.4 is used directly — no system Lua library needed.
- The `data/` directory mirrors the SD card filesystem structure from the device. Default files
  (profiles.ini, systemConfig.ini) are provided for immediate testing.
- The `src/` symlink points to `../T-HMI-PEPmonitor/src/` — changes to the original source
  are automatically picked up by the compat build.

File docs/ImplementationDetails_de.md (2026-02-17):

## Luftdruck-Sensor-Datenfilterung

Die Rohdaten des Luftdrucksensors haben ein paar Probleme, die durch Software behandelt werden.

# Der atmosphärische Umgebungsdruck variiert

Abhängig von Höhe, Temperatur und Wetter variiert der Luftdruck rund um das Gerät. Um dafür zu korrigieren tariert sich das PEPit direkt nach dem Start auf den Umgebungsdruck. Das passiert innerhalb der ersten Sekunde nach dem Einschalten. Wenn das Logo oder das Hauptmenü erscheint ist die Tarierung schon abgeschlossen.

Damit die Tarierung korrekt funktioniert muss der Luftweg zum Luftdrucksensor den gleichen Luftdruck haben wie die Umgebungsluft. Dafür lässt man beim Einschalten des Gerätes am Besten den Luftschlauch abgesteckt. Alternativ muss man darauf achten, dass der Luftschlauch knickfrei ist und nicht zugehalten wird. Das Inhalations- oder Therapiegerät darf sich nicht im Mund befinden.

Sollte die Tarierung falsch ausgeführt werden, kann es passieren dass das Gerät sich auf den falschen Wert tariert und es dann insbesondere am Anfang der Übungen falsche Werte misst.

# Der gemessene Druck hat falsche Spikes

Durch das Inhalieren/Exhalieren ändert sich nicht nur der Druck im Luftschlauch, sondern auch die Geschwindigkeit der Luft im Schlauch. Wird der Atemzug plötzlich unterbrochen, dann "schlägt" die Luft im Luftschlauch plötzlich zurück. Das führt zu sehr kurzen aber sehr starken Ausschlägen am gemessenen Luftdruck, oft über 500mBar.

Um diese Messwerte zu korrigieren werden zwei Mechanismen eingesetzt.

- Werte über +-200mBar werden ignoriert. Diese Grenze liegt weit über allen Werten die normal in der Nutzung vorkommen sollten, können also als Sensor-Artefakte ignoriert werden.
- Es wird ein Rolling Average Filter verwendet um den Sensor-Output zu glätten. Dazu werden die letzten gemessenen Werte gesammelt und ein Durchschnitt dieser letzten Werte als tatsächlicher Output zurückgeliefert.

# Der Sensorwert kann driften

Bei starken Temperaturänderungen (z.B. durch Lüften) oder wenn die Batteriespannung unter 3.6V fällt, kann es dazu kommen dass der Sensorwert driftet. Das ist eine langsame graduelle Änderung aller gemessenen Werte. So kann der gemessene Wert z.B. langsam um ein paar mBar nach oben oder unten wandern.

Um das zu korrigieren tariert die Software automatisch nach. Das passiert jedes Frame, also normalerweise zwischen 15-80 Mal pro Sekunde.

Da der Sensordrift langsam und graduell passiert, ist auch die Autotarierung graduell. Bei jeder Messung wird die Tarierung leicht angepasst.

Ein Threshold-Filter sorgt dabei dafür, dass der Ruhezustand erkannt wird und die Tarierung in diesem Zustand passiert.

Um Fehler bei der initialen Tarierung während dem Hochfahren des Geräts auszugleichen, wird auch bei höheren Drücken autotariert, dort aber sehr langsam um keine Auswirkung auf tatsächliche Atemzüge zu haben.

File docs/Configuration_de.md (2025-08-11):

# Option A: Konfiguration per Konfigurator

Um das PEPit per Konfigurator zu konfigurieren muss sich die SD-Karte im PEPit befinden und das PEPit per USB-Kabel mit einem Computer verbunden werden.

Dann muss man am Computer in einem kompatiblen Browser, der WebSerial unterstützt, geöffnet werden. Getestete Browser sind:

- Chrome
- Chromium
- Vivaldi
- Edge
- Opera

Nicht unterstützt wird Firefox, da diesem die benötigte Schnittstelle fehlt.

In diesem Browser öffnet man dann [die Konfigurator-Website](https://dak.lima-city.at). Dort folgt man dann den Anweisungen und konfiguriert die Systemkonfiguration sowie die Profile.

# Option B: Manuelle Konfiguration per Konfigurationsdatei

Um das PEPit per Konfigurationsdatei zu konfigurieren muss das Gerät abgeschaltet und die SD-Karte mit einem Computer verbunden werden.

Auf der SD-Karte befinden sich zwei Dateien, die angepasst werden müssen.

## systemconfig.ini

Hier ist eine Beispiel-systemconfig.ini:

    [system]
    # Wifi credentials used for connecting to trampoline
    # and for getting time and date to log physiotherapy executions
    # Up to 3 wifi access points can be configured
    # WLAN Name und Password fuer die Verbindung zum Trampolinsensor
    # sowie um Zeit und Datum fuer zum Aufzeichnen der Therapie zu empfangen
    # Bis zu drei WLAN-Verbindungen können konfiguriert werden
    wifiSSID=
    wifiPassword=
    wifiSSID2=
    wifiPassword2=
    wifiSSID3=
    wifiPassword3=
    # IP address of the trampoline sensor
    # IP-Adresse des Trampolinsensors
    trampolineIp=
    # Log executions to /executionsLog.txt on the SD card.
    # Zeichne Uebungen auf und schreibe sie nach /executionsLog.txt
    # auf der SD-Karte.
    logExecutions=true
    # Timezone difference from UTC in minutes
    # Zeitzonenverschiebung zu UTC in Minuten
    timezoneOffset=60
    # Simulate PEP exercises
    # Simuliere PEP-Uebungen
    simulateBlowing=false
    # Simulate Trampoline exercises.
    # If no Wifi credentials or Trampoline IP are used,
    # simulateTrampoline will be activated automatically.
    # Simuliere Trampolinuebungen.
    # Wurden keine Wifi-Zugangsdaten oder keine Trampolin-IP
    # eingegeben, wird die Trampolinsimulierung automatisch
    # aktiviert. 
    simulateTrampoline=true

### WLAN-Konfiguration

Um automatisch nach Updates zu suchen und um im Ausführungs-Log Datum und Uhrzeit einzutragen wird WLAN benötigt.

Dazu muss der WLAN-Netzwerkname ohne Leerzeichen direkt nach `wifiSSID=` und das Passwort nach `wifiPassword=` eingefügt werden:

    wifiSSID=WlanName123
    wifiPassword=WlanPasswort123

Es können bis zu drei WLANs konfiguriert werden.

Dabei sind folgende Einschränkungen zu beachten:

- Das WLAN muss 2.4GHz-fähig sein. Die meisten WLANs sind so eingestellt, dass sie ein 2.4GHz-Netz bereit stellen. Sollte keine Verbindung hergestellt werden können, dann sollte man die passende Einstellung in den Router-Einstellungen kontrollieren.
- WLANs mit Username+Passwort werden aktuell nicht unterstützt.
- WLANs, bei denen man im Browser die AGBs akzeptieren muss, werden mangels Browser nicht unterstützt.

Sollte man kein kompatibles WLAN zur Verfügung haben (z.B. im Spital), dann kann man stattdessen einen Handy-Hotspot verwenden. Dabei ist besonders darauf zu achten, dass man in den Hotspot-Einstellungen 2.4GHz auswählt und nicht 5GHz.

### Simulierte Sensoren

    simulateBlowing=false
    simulateTrampoline=true

Für einen Demo-Betrieb (wenn man z.B. die Funktionaität herzeigen oder Spiele entwickeln möchte) kann man Sensorsimulation einschalten.

`simulateBlowing=true` bedeutet, dass der Luftdrucksensor für Exhalation und Inhalation nicht verwendet wird und stattdessen simulierte Sensordaten verwendet werden. Im Normalbetrieb sollte das also auf `simulateBlowing=false` gesetzt werden.

`simulateTrampoline=true` bedeutet, dass statt einem Trampolinsensor simulierte Daten verwendet werden. Da der Trampolinsensor aktuell noch nicht veröffentlicht wurde, soll im Normalbetrieb dieser Wert auf `simulateTrampoline=true` gesetzt werden. In diesem Modus kann ein Trampolin-Spiel als Timer für das Trampolinspringen verwendet werden.

## profiles.ini

Die profiles.ini beinhaltet die Physiotherapie-Profile. Ein Profil beinhaltet einen oder mehrere Tasks, die vorgeben welche Art von Therapie ausgeführt werden soll.

Jedes Profil beginnt mit so einem Profil-Tag:

    [profile_0]

Die Zahl nach `profile_` muss einzigartig und lückenlos fortlaufend sein. Das erste Profil muss `[profile_0]` sein. Es können aktuell bis zu 8 Profile auf einem Gerät konfiguriert werden.

Auf das Profile-Tag folgen die generellen Einstellungen des Profils:

    name=PEP S
    imagePath=/gfx/profile_pep_s.bmp
    cycles=3

Der Wert nach `name=` wird im Hauptmenü angezeigt und im Ausführungs-Log nach vollständiger Ausführung gespeichert.

Der Wert nach `imagePath=` muss mit `/` beginnen und gibt den Pfad zu einem Bild auf der SD-Karte an. Das Bild sollte maximal 32x48 Pixel groß sein und muss im BMP-Format gespeichert werden.

Der Wert nach `cycles=` gibt an wie oft die gesamte folgende Therapieroutine wiederholt wird.

### Tasks

Ein Task gibt eine bestimmte Tätigkeit an, die genau gleich mehrfach ausgeführt werden kann. Ein Profil kann bis zu 10 Tasks beinhalten. Diese müssen wieder beginnend bei 0 lückenlos fortlaufend und einzigartig numeriert werden.

Dabei gibt es vier verschiedene Task-Arten die unterschiedlich konfiguriert werden müssen.

#### PEP Tasks

PEP Tasks sind Tasks bei denen gegen einen Widerstand ausgeatmet werden muss, z.B. mit einem Pari PEP S, einem RC Cornet/RC Cornet+ oder einem PEP/RMT.

    task_0_type=pepLong
    task_0_minStrength=100
    task_0_targetStrength=170
    task_0_repetitions=10
    task_0_time=5000
    task_0_changeText=2.5mm
    task_0_changeImagePath=/gfx/peps_2.5.bmp
    task_1_type=pepShort
    task_1_minStrength=170
    task_1_targetStrength=300
    task_1_repetitions=5
    task_1_time=1000
    task_1_changeText=5mm
    task_1_changeImagePath=/gfx/peps_5.bmp

Hier sehen wir ein Profil, welches aus zwei Tasks besteht. Einem langen Ausatmen mit 2.5mm Stenose für 5 Sekunden bei 17 Millibar welches 10x wiederholt wird, und einem kurzen, festen Ausblasen mit 5mm Stenose für 1 Sekunde bei 30 Millibar, welches 5x verwendet wird.

`task_0_type=` teilt dem Spiel mit, was für eine Art PEP-Task verwendet wird. Besteht das Profil nur aus Tasks mit gleich langem Ausatmen, dann verwendet man hier `task_0_type=pepEqual`. Besteht das Profil hingegen aus abwechselnden Segmenten mit langem und mit kurzem Ausathmen, dann verwendet man für den einen Task `task_0_type=pepLong` und für den anderen Task `task_1_type=pepShort` respektive. (Aus Rückwärtskompatibilitätsgründen sind alternativ auch die Werte `task_0_type=equalBlows`, `task_0_type=longBlows` und `task_0_type=shortBlows` erlaubt. Die sind in ihrer Funktion identisch zu den neueren `pepEqual`, `pepLong` und `pepShort`.)

`task_0_minStrength` gibt an, welcher Druck allermindestens gehalten werden muss. Fällt der Druck darunter gilt die Exhalation als abgebrochen bzw. fehlgeschlagen. Die Einheit hierfür sind Zehntel-Millibar. Für einen Druck von 10 Millibar muss man hier also `task_0_minStrength=100` eingeben.

`task_0_targetStrength` gibt an, welcher Druck idealerweise gehalten werden soll. Wird der Druck erreicht, dann ist die Druckleiste am unteren Rand des Bildschirms voll und manche Spiele belohnen es, wenn dieser Druck erreicht wird. Die Einheit hierfür sind Zehntel-Millibar. Für einen Druck von 17 Millibar muss man hier also `task_0_targetStrength=170` eingeben.

`task_0_repetitions=` gibt an, wie oft ausgeatmet werden muss um den Task fertig zu machen.

`task_0_time=` gibt an, wie viele Millisekunden der Minimaldruck mindestens gehalten werden muss. Für 5 Sekunden muss man also `task_0_time=5000` eintragen.

`task_0_changeText=` gibt an, welcher Text am Bildschirm erscheint, wenn zu diesem Task gewechselt wird. Damit kann man z.B. die Nutzerin/den Nutzer anweisen auf eine andere Stellung des Geräts zu wechseln.

`task_0_changeImagePath=` gibt an, welches Bild für den Wechsel angezeigt wird. Das Bild muss 320x240 Pixel groß sein und als BMP abgespeichert werden. Der angegebene Pfad muss mit `/` beginnen und auf eine Datei auf der SD-Karte zeigen.

#### Inhalation Tasks

Inhalations-Tasks werden in Kombination mit Inhalationsgeräten wie dem Pari Boy + LC-Sprint oder dem Pari eFlow Rapid verwendet. Um den PEPit mit diesen Inhalationsgeräten zu verbinden wird das Mittelteil des PEP S auf das kleinste Loch gestellt und zwischen das Reservoir und das Mundstück des Inhalationsgeräts gesteckt. Dabei gibt der PEP S-Mittelteil keinen Widerstand sondern wird nur als Adapter für den Schlauch verwendet.

Inhalationstasks sollten der einzige Task in einem Profil sein und `cycles=` sollte auf `cycles=1` gesetzt sein.

  task_0_type=inhalation
  task_0_minRepetitions=20
  task_0_time=2500
  task_0_minStrength=15
  task_0_targetStrength=30

`task_0_minRepetitions=` gibt an, wie viele Atemzüge mindestens gemacht werden müssen, damit der "Fertig"-Knopf eingeblendet wird und der Task beendet werden kann.

Die anderen Werte sind identisch in ihrer Bedeutung zu den Werten aus den PEP Tasks

#### Kombinierte Inhalation + PEP Tasks (verfügbar ab Version 5.0)

Der Pari PEP S kann in seiner Gesamtheit auf einen LC-Sprint oder eFlow Rapid aufgesteckt werden. Dabei wird nicht nur das Mittelstück verwendet. Stattdessen ersetzt der PEP S das reguläre Mundstück des Inhalationsgerätes. Auf einen Inhalations-Zug wird dann eine Ausatmung gegen den Widerstand des PEP S verwendet. Wie bei der Inhalation sollte ein `inhalationPep` Task der einzige Task in einem Profil sein und `cycles=1` sollte gesetzt sein.

    task_0_type=inhalationPep
    task_0_minRepetitions=10
    task_0_inhalationTime=2500
    task_0_inhalationMinStrength=15
    task_0_inhalationTargetStrength=30
    task_0_exhalationMinStrength=100
    task_0_exhalationTargetStrength=170
    task_0_exhalationTime=5000

`task_0_minRepetitions=`, `task_0_inhalationTime=`, `task_0_inhalationMinStrength=` und `task_0_inhalationTargetStrength=` funktionieren wie bei dem Inhalationstask.

`task_0_exhalationMinStrength=`, `task_0_exhalationTargetStrength=` und `task_0_exhalationTime=` funktionieren wie bei PEP Tasks.

#### Trampolin Task

Der Trampolinsensor ist aktuell noch nicht veröffentlicht und befindet sich noch in Arbeit. Der Sensor ist ein eigenständiges Gerät, welches sich per Bluetooth mit dem PEPit verbindet. Er erkennt wie oft und wie hoch die Spielerin/der Spieler am Trampolin springt. Da dieser Sensor allerdings noch nicht verfügbar ist, wird aktuell das Trampolin simuliert. In diesem Modus funktioniert das PEP als ein Timer für das Trampolinspringen.

    task_0_type=trampoline
    task_0_time=300000

`task_0_time=` gibt an, wie viele Millisekunden gehüpft werden muss. Für 5 Minuten ist das also `task_0_time=300000`.

## Spielstände zurücksetzen

Wird das PEPit (z.B. in einem Klinik-Setting) an einen anderen Nutzer weitergegeben, kann es sinnvoll sein die gespeicherten Spielstände zurückzusetzen.

Dafür muss im Hauptverzeichnis der SD-Karte eine leere Textdatei mit dem Namen `resetSaves` erstellt werden. Die SD-Karte wird dann wieder in das PEPit gesteckt und das PEPit wird gestartet.

Das PEPit löscht dann die Spielstände und die Datei und kann an den nächsten Nutzer weiter gegeben werden.

Nächster Schritt: [Verbinden mit Physiotherapie-Geräten](Devices_de.md)

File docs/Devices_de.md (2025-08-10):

# Verbinden mit Physiotherapie-Geräten

## PEP S

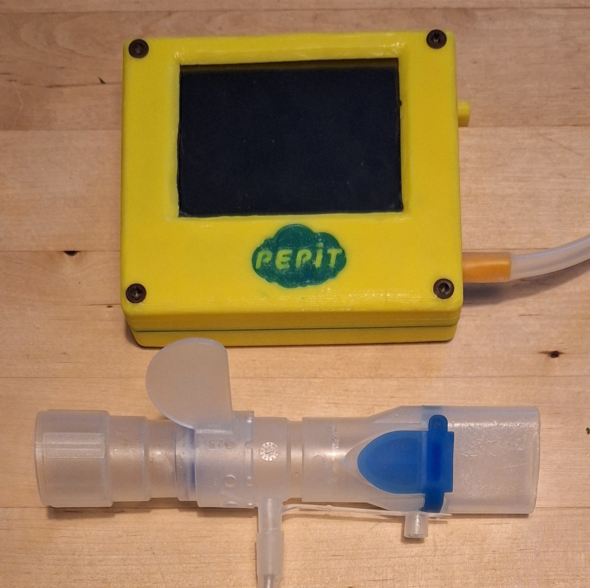
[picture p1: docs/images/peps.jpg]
PEPit mit PEP S


Die einfachste Konfiguration. Zur Verwendung mit dem "PEP S"-Profil.

## eFlow / LC Sprint

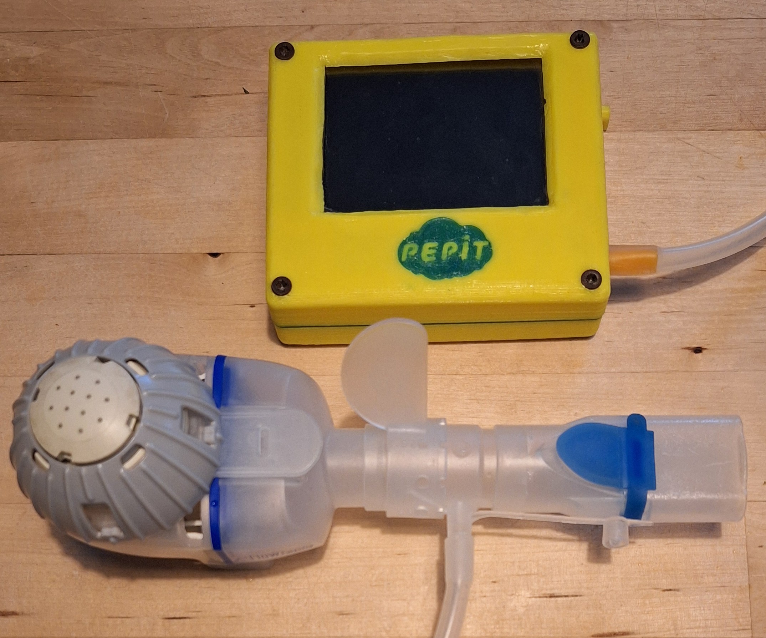
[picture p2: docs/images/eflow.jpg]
PEPit mit eFlow


Zur Verwendung mit dem "Inhalation"-Profil.

Von links nach rechts verwendet man das Reservoir des eFlow oder LC Sprint, dann den Ring und das Mittelstück des Pari PEP S und zuletzt das Mundstück des eFlow oder LC Sprint mit Ventil.

Das Mittelstück des PEP S wird nur als Schlauchadapter verwendet und muss auf die kleinste Stenose gesetzt werden.

## eFlow / LC Sprint + PEP S

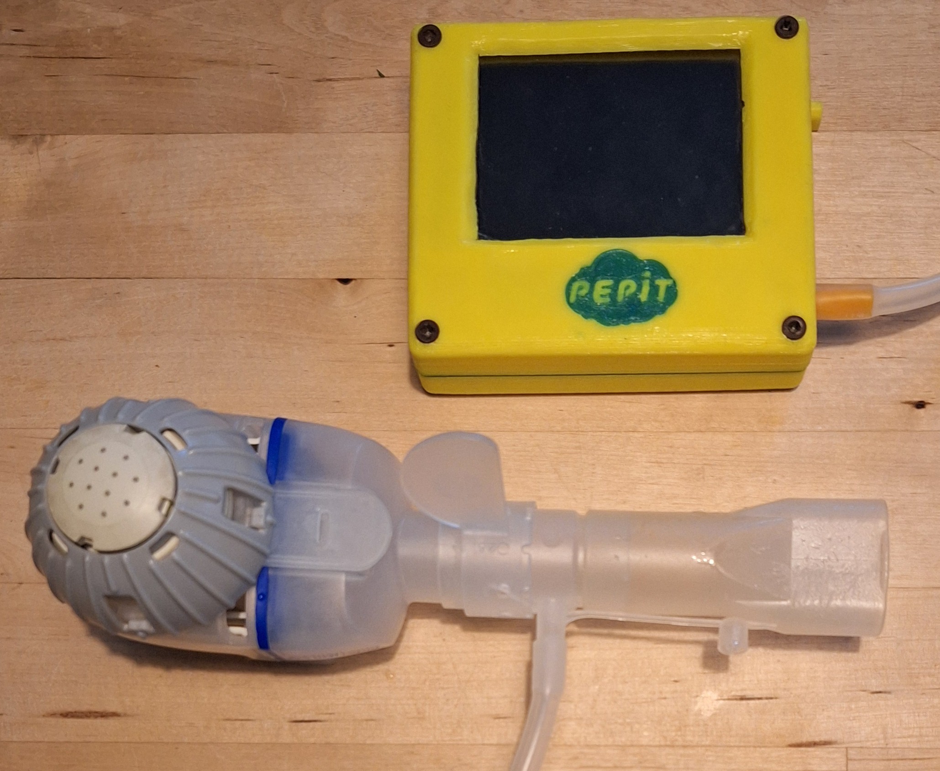
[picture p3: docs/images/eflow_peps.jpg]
PEPit mit eFlow und PEP S


Zur Verwendung mit dem "Inhalation+PEP"-Profil.

Von links nach rechts verwendet man das Reservoir des eFlow oder LC Sprint, dann den Ring und das Mittelstück des Pari PEP S und zuletzt das Mundstück des PEP S ohne Ventil.

Beim Einatmen wird inhaliert, beim Ausatmen wird das PEP S als Luftwiderstand verwendet. Die Stenose muss entsprechend eingestellt werden.

## RC Cornet / RC Cornet+

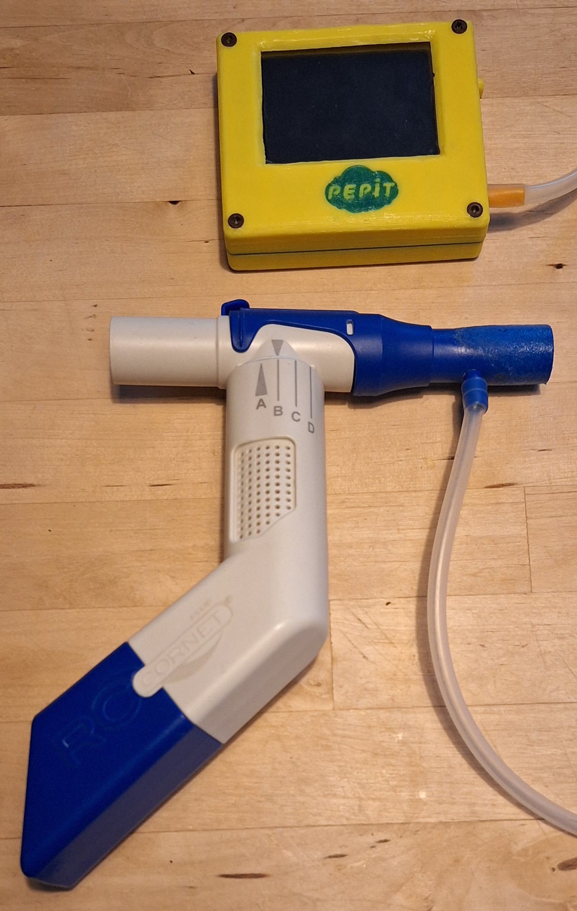
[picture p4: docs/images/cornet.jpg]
PEPit mit RC Cornet+


Zur Verwendung mit dem "RC Cornet"-Profil.

In das Mundstück des RC Cornet/RC Cornet+ wird der ["RC-Cornet® Druck-Mess-Adapter"](https://www.cegla.de/produkte/zubehoer/) gesteckt, an den der Luftschlauch des PEP S angeschlossen wird.

## eFlow / LC Sprint + RC Cornet / RC Cornet+

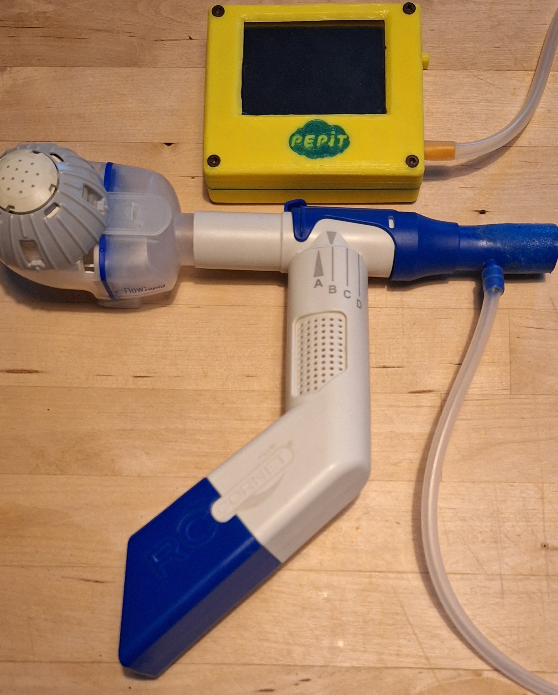
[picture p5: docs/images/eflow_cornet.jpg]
PEPit mit eFlow und RC Cornet+


Zur Verwendung mit dem "Inhalation+PEP"-Profil.

Von links nach rechts verwendet man das Reservoir des eFlow oder LC Sprint, dann das RC Cornet/RC Cornet+ und zuletzt den Druck-Mess-Adapter.

Beim Einatmen wird inhaliert, beim Ausatmen wird das RC Cornet als Luftwiderstand verwendet.

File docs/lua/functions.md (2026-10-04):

# Lua Functions

This document lists every C function that is exposed to Lua games via `lua_register()` in
[`gameLua.cpp`](../../T-HMI-PEPmonitor/src/games/gameLua.cpp). All functions are registered as **global**
functions on the Lua state, so they can be called directly by name from any game script.

The standard Lua libraries `table`, `string` and `math` are also available (see
[`gameLua.cpp:942-948`](../../T-HMI-PEPmonitor/src/games/gameLua.cpp#L942)).

> **Note on types.** The C wrappers read arguments with `luaL_check*` / `luaL_opt*`. In practice
> Lua numbers are passed for all numeric parameters. "int" and "float" below describe the C type
> the wrapper expects; from Lua you can simply pass a number.

## Contents

- [System & Debug](#system--debug)
- [Scripting](#scripting)
- [Sprites — Loading & Freeing](#sprites--loading--freeing)
- [Sprites — Drawing](#sprites--drawing)
- [Sprites — Info & Draw Target](#sprites--info--draw-target)
- [Mode 7 (3D Ground)](#mode-7-3d-ground)
- [Graphics Primitives](#graphics-primitives)
- [Text](#text)
- [Preferences (Persistent Storage)](#preferences-persistent-storage)
- [Game Flow](#game-flow)
- [Math Utilities](#math-utilities)
- [Touch Input](#touch-input)
- [Joystick Input](#joystick-input)
- [Road (OutRun-style)](#road-outrun-style)
- [Flag Constants](#flag-constants)

---

## System & Debug

### `SerialPrintln(s)`
Prints a string to the serial console followed by a newline.

| Param | Type | Description |
|---|---|---|
| `s` | string | Text to print |

**Returns:** nothing.

### `SerialPrint(s)`
Prints a string to the serial console without a newline.

| Param | Type | Description |
|---|---|---|
| `s` | string | Text to print |

**Returns:** nothing.

### `GetFreeRAM()`
**Returns:** free internal heap in bytes (number).

### `GetFreePSRAM()`
**Returns:** free PSRAM in bytes (number).

### `DisableCaching()`
Disables the Lua script source cache. By default game scripts are read from the SD card once and
cached in RAM for the lifetime of the game; calling this makes subsequent `RunScript` / script
loads re-read from disk.

**Returns:** nothing.

---

## Scripting

### `RunScript(path)`
Loads and executes another Lua script. The path is resolved **relative to the current game's
directory** (the directory of `init.lua`).

| Param  | Type | Description |
|---|---|---|
| `path` | string | Script path relative to the game folder  |

**Returns:** nothing. Errors are reported on the serial console (and, in strict mode, abort).

---

## Sprites — Loading & Freeing

Sprites are stored in a fixed pool of **200** slots (`SPRITE_COUNT_LIMIT`). Loading a sprite
returns an integer **handle** (the slot index) that is used by all the drawing functions. A
failed load returns `-1`.

### `LoadSprite(path, options = 0, maskingColor = -1)`
Loads a static BMP sprite into the first free slot.

| Param | Type | Default | Description |
|---|---|---|---|
| `path` | string | — | BMP path relative to the game folder |
| `options` | int | `0` | Bitmap options (see [Flag Constants](#flag-constants))  |
| `maskingColor` | int | `-1` | Color treated as transparent, or `-1` for none |

**Returns:** sprite handle (int), or `-1` on failure.

### `LoadAnimSprite(path, frameW, frameH, options = 0, maskingColor = -1)`
Loads an animated (sprite-sheet) BMP sprite. The sheet is divided into frames of `frameW` ×
`frameH` pixels, laid out left-to-right, top-to-bottom.

| Param | Type | Default | Description |
|---|---|---|---|
| `path` | string | — | BMP path relative to the game folder |
| `frameW` | number | — | Width of a single frame in pixels |
| `frameH` | number | — | Height of a single frame in pixels |
| `options` | int | `0` | Bitmap options (see [Flag Constants](#flag-constants))  |
| `maskingColor` | int | `-1` | Color treated as transparent, or `-1` for none |

**Returns:** sprite handle (int), or `-1` on failure.

### `FreeSprite(handle)`
Frees a previously loaded sprite, making its slot available again. If the sprite is currently the
active draw target, the draw target is reset to the main framebuffer.

| Param | Type | Description |
|---|---|---|
| `handle` | int  | Sprite handle |

**Returns:** nothing.

### `GetFreeSpriteSlots()`
**Returns:** number of currently free sprite slots (int, 0–200).

---

## Sprites — Drawing

All drawing functions render to the **current draw target** (see
[SetDrawTargetSprite](#setdrawtargetspritehandle) /
[SetDrawTargetFramebuffer](#setdrawtargetframebuffer)).

### `DrawSprite(handle, x, y, [opts])`
Draws a sprite (or a single frame of an animated sprite) at position `(x, y)` with optional
scaling, rotation, and opacity. This is the unified drawing function that replaces the former
`DrawAnimSprite`, `DrawSpriteScaled`, `DrawAnimSpriteScaled`, `DrawSpriteScaledRotated`, and
`DrawAnimSpriteScaledRotated`.

| Param | Type | Default | Description |
|---|---|---|---|
| `handle` | int | — | Sprite handle |
| `x` | number | — | Destination X coordinate |
| `y` | number | — | Destination Y coordinate |
| `opts` | table  | `nil` | Optional drawing options (see below) |

**Options table fields:**

| Field | Type | Default | Description |
|---|---|---|---|
| `scaleX` | number | `1.0` | Horizontal scale factor |
| `scaleY` | number | `1.0` | Vertical scale factor |
| `angle` | number | `0.0` | Rotation in radians |
| `frame` | int | `-1` | Frame index for animated sprites (`-1` = whole sprite) |
| `flags` | int | `0` | Draw flags (see [Flag Constants](#flag-constants)) |
| `alpha` | number | `1.0` | Opacity, `0` (transparent)–`1` |

The function automatically selects the most efficient rendering path based on which options
are set (plain blit → scaled → transformed).

**Examples:**

```lua
-- Simple draw
DrawSprite(1, 100, 200)

-- With alpha
DrawSprite(1, 100, 200, {alpha = 0.5})

-- Scaled
DrawSprite(1, 100, 200, {scaleX = 2.0, scaleY = 2.0})

-- Rotated and scaled
DrawSprite(1, 100, 200, {scaleX = 1.5, angle = math.pi / 4})

-- Animated sprite, frame 3, centered
DrawSprite(2, 100, 200, {frame = 3, flags = ALIGN_H_CENTER | ALIGN_V_CENTER})
```

**Returns:** nothing.

---

## Sprites — Info & Draw Target

### `SpriteWidth(handle)`
**Returns:** width of the sprite (or a single frame for animated sprites) in pixels.

### `SpriteHeight(handle)`
**Returns:** height of the sprite (or a single frame for animated sprites) in pixels.

### `SetDrawTargetSprite(handle)`
Sets the current draw target to a sprite, so subsequent drawing calls render into that sprite's
buffer instead of the screen. If `handle` is invalid, the target resets to the framebuffer.

| Param | Type | Description |
|---|---|---|
| `handle` | int  | Sprite handle |

**Returns:** nothing.

### `SetDrawTargetFramebuffer()`
Sets the current draw target back to the main framebuffer (the screen).

**Returns:** nothing.

---

## Mode 7 (3D Ground)

Mode 7 rendering produces a pseudo-3D ground plane (à la classic racing games) from a texture
sprite, using a virtual camera.

### `DrawMode7(textureHandle, camX, camY, camHeight, yawAngle, zoom, horizonHeight, startY, endY)`
Renders the Mode 7 ground into the region between `startY` and `endY`.

| Param | Type | Description |
|---|---|---|
| `textureHandle` | int | Handle of the ground texture sprite |
| `camX` | number | Camera world X position |
| `camY` | number | Camera world Y position |
| `camHeight` | float  | Camera height above the ground plane |
| `yawAngle` | float  | Camera yaw (rotation) in radians |
| `zoom` | float  | Zoom / focal factor |
| `horizonHeight` | float  | Y position of the horizon line |
| `startY` | float  | Top screen row to start rendering at |
| `endY` | float  | Bottom screen row to render up to |

**Returns:** nothing.

### `Mode7WorldToScreen(worldX, worldY, camX, camY, camHeight, yawAngle, zoom, horizonHeight, startY, endY)`
Projects a world-space point onto the screen using the same camera parameters as `DrawMode7`.

| Param | Type | Description |
|---|---|---|
| `worldX` | number | World X of the point |
| `worldY` | number | World Y of the point |
| `camX` | number | Camera world X position |
| `camY` | number | Camera world Y position |
| `camHeight` | float  | Camera height above the ground plane |
| `yawAngle` | float  | Camera yaw in radians |
| `zoom` | float  | Zoom / focal factor |
| `horizonHeight` | float  | Y position of the horizon line |
| `startY` | float  | Top screen row |
| `endY` | float  | Bottom screen row |

**Returns:** three values — `screenX` (int), `screenY` (int), `scale` (float).

```lua
sx, sy, s = Mode7WorldToScreen(wx, wy, camX, camY, camH, yaw, zoom, horizon, startY, endY)
```

---

## Graphics Primitives

All primitives draw to the current draw target. Colors are 16-bit RGB565 values (e.g. `TFT_RED`).

### `DrawString(str, x, y)`
Draws text at `(x, y)`. Multi-line strings (containing `\n`) are supported; each line advances by
one font height.

| Param | Type | Description |
|---|---|---|
| `str` | string | Text to draw |
| `x` | number | X coordinate |
| `y` | number | Y coordinate |

**Returns:** nothing.

### `DrawRect(x, y, w, h, color)`
Draws an unfilled rectangle outline.

| Param | Type | Description |
|---|---|---|
| `x` | number | Top-left X |
| `y` | number | Top-left Y |
| `w` | number | Width |
| `h` | number | Height |
| `color` | int | RGB565 color |

**Returns:** nothing.
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

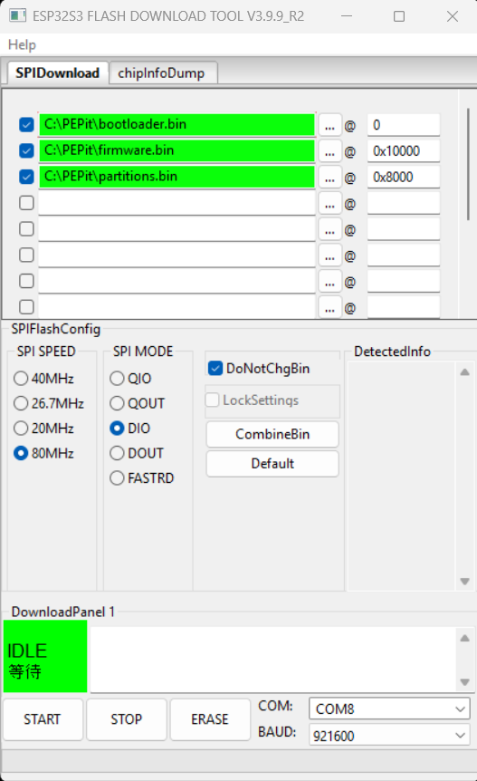
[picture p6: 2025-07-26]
docs/images/flashdownloadtool2.png

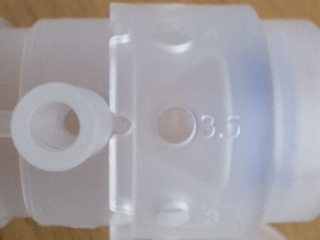
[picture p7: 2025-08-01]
SDCardContent/gfx/peps_3.5.bmp

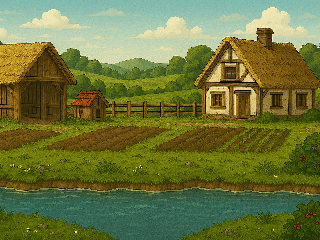
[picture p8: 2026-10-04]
SDCardContent/games/farm/gfx/farm2.bmp

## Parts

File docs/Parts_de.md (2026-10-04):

# Benötigte Werkzeuge

- Schraubenzieher
- Lötkolben mit Lötzinn
- Werkzeug zum Abisolieren von Kabeln
- 3D-Drucker (optional)
- PC mit Windows (Andere Betriebssysteme sind möglich, werden aber in diesem Guide aktuell nicht behandelt)
- SD-Karte zu USB Adapter (falls man im PC keinen SD-Karten-Slot hat)
- Patafix oder doppelseitiges Klebeband

# Benötigte Bauteile

## Elektronische Bauteile

- LILLYGO T-HMI: https://lilygo.cc/products/t-hmi
- Luftdrucksensor: https://de.aliexpress.com/item/1005006421627550.html

Luftdrucksensor
- 1S Akku mit PH2.0 Anschluss, mindestens 200mA (https://de.aliexpress.com/item/1005007256417369.html)
- MicroSD-Karte mit mindestens 1GB und maximal 32GB.
- M5stack Joystick2

## Schrauben

- 4x M3x25 Schrauben
- 4x M3 Muttern, viereckig
- 4x M2x10 Schrauben

## Sonstiges

- Doppelseitiges Klebeband, am Besten Tesa Powerstrips Small

## 3D-Druck

- Obere Hälfte: (https://github.com/Dakkaron/T-HMI-PEPmonitor/blob/main/3DPrint/T_HMI_PEP_case_v3.2_top.stl)
- Untere Hälfte: (https://github.com/Dakkaron/T-HMI-PEPmonitor/blob/main/3DPrint/T_HMI_PEP_case_v3.2_bottom_with_tpu.stl)
- Schlauch-Adapter: (https://github.com/Dakkaron/T-HMI-PEPmonitor/blob/main/3DPrint/PEP_adapter.stl)

Der Schlauchadapter muss mit flexiblem Material (z.B. TPU- oder TPE-Filament) gedruckt werden.

Sollte kein 3D-Drucker zur Verfügung stehen, bietet sich der Druckservice von [JLC3DP](https://jlc3dp.com) an.

### Anleitung für JLC3DP

1. LadenSie die drei STL Dateien aus dem letzten Punkt herunter.
2. Öffnen sie [https://jlc3dp.com](https://jlc3dp.com) in ihrem Browser.
3. Klicken sie auf "Order Now"
4. Klicken sie auf "Add 3D Files" und fügen sie alle drei STL-Dateien nacheinander hinzu.
5. Für die beiden Gehäuseteile wählen sie einen passenden Druckprozess und Material aus. `FDM(Plastic)` -> `PLA` funktioniert gut, aber andere Materialien sollten auch verwendbar sein.
6. Für den PEP_adapter.stl wählen sie `FDM(Plastic)` -> `TPU`
7. Farben können beliebig gewählt werden.
8. Drücken Sie "Save to cart" und folgen Sie dem Bestellprozess.
9. `Global Direct Line`-Versand ist mit Abstand der Billigste, dauert dafür normal 1-2 Wochen.

Nächster Schritt: [Software installieren](Software_de.md)

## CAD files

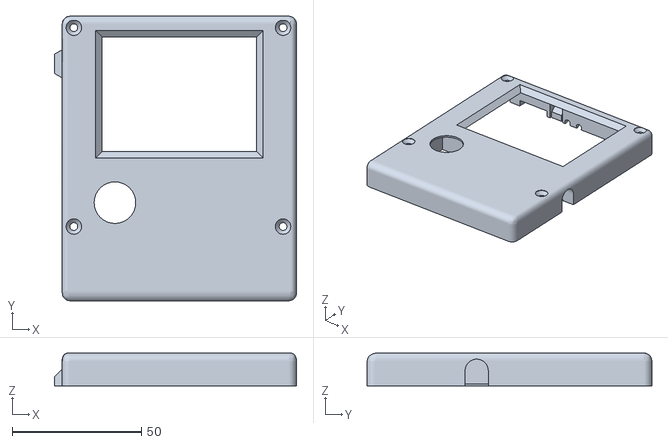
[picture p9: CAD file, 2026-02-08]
3DPrint/T_HMI_PEP_case_v4.2_top.stl
93.7 x 110.2 x 12.8

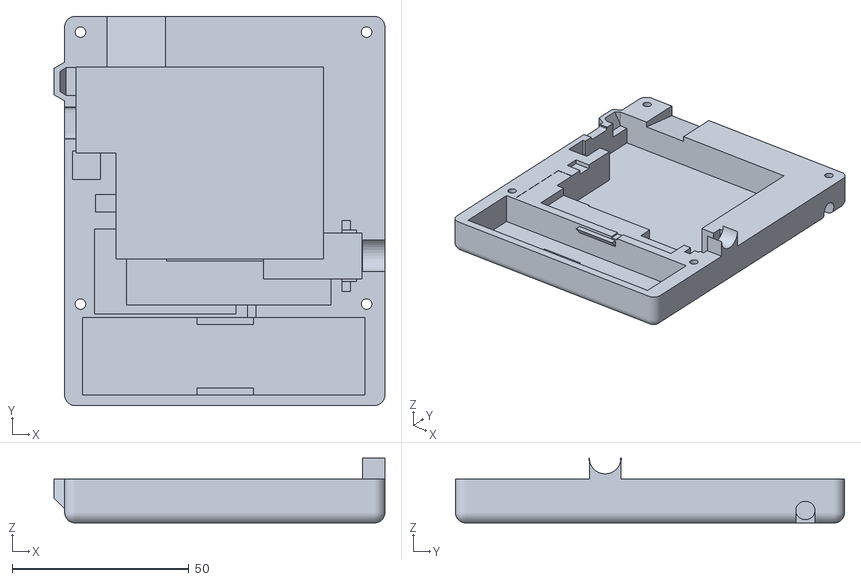
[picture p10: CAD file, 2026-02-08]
3DPrint/T_HMI_PEP_case_v4.2_bottom_with_squarenuts_nobatterylid.stl
93.7 x 110.2 x 18.4

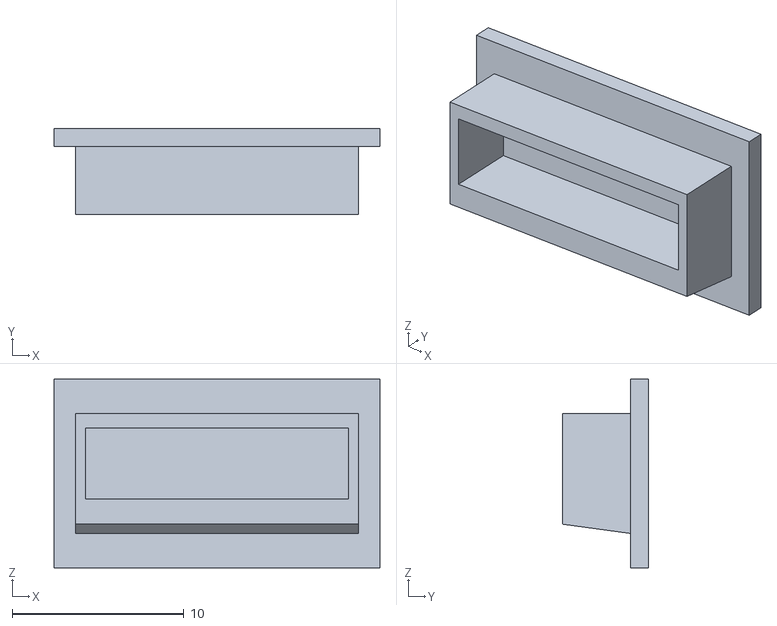
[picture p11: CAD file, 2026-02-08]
3DPrint/T_HMI_PEP_case_v4.2_microSD_cover.stl
19.0 x 5.00 x 11.0

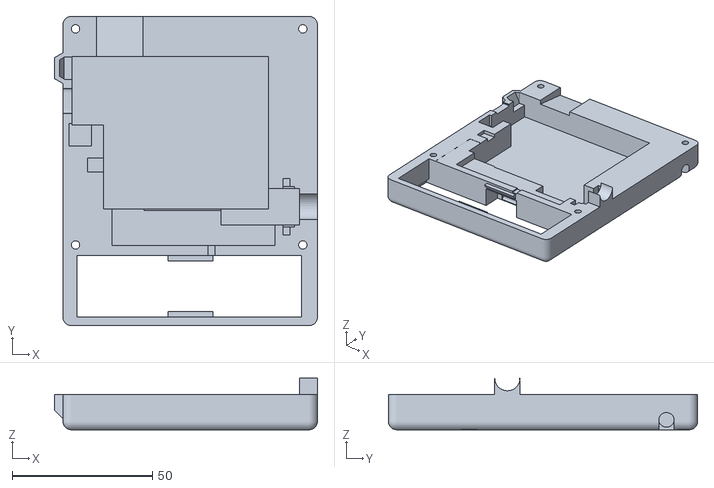
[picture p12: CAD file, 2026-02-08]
3DPrint/T_HMI_PEP_case_v4.2_bottom_with_squarenuts.stl
93.7 x 110.2 x 18.4

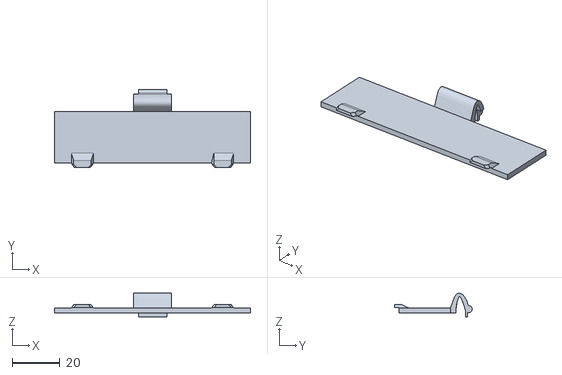
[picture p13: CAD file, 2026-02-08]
3DPrint/T_HMI_PEP_case_v4.2_battery_lid.stl
81.8 x 32.4 x 9.84

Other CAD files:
3DPrint/T_HMI_PEP_case_v4.2_bottom_with_hexnuts.stl
3DPrint/T_HMI_PEP_case_v4.1.blend
3DPrint/T_HMI_PEP_case_v4.2.blend

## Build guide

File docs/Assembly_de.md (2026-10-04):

# Löten

- Das bei dem T-HMI mitgelieferte Grove-Kabel (das Kabel mit den vier Adern) in der Mitte durchschneiden und die Adern rund 5mm tief abisolieren.
- Die vier Adern in der folgenden Reihenfolge an den Luftdrucksensor anlöten:
   - Schwarz -> GND
   - Rot -> VCC
   - Gelb -> OUT
   - Weiß -> SCK

# Joystick-Kabel vorbereiten

- Der M5stack Joystick2 hat keine Power-Saving-Features. Deswegen muss das Grove-Kabel umgebaut werden, damit das T-HMI den Joystick abschalten kann.
- Dazu muss der rote Draht aus dem Grove-Connector entfernt werden und auf die zweite Position von rechts auf einem ansonsten leeren Grove-Connector verbunden werden.

# Verkablen

- Den Grove-Connector vom Luftdrucksensor in den mittleren Grove-Steckplatz am T-HMI anschließen.
- Den Grove-Connector vom M5stack Joystick2, der noch drei Drähte hat, mit dem linken Grove-Steckplatz (IO15 und IO16) verbinden.
- Den Grove-Connector vom M5stack Joystick2, der einen Draht hat, mit dem rechten Grove-Steckplatz (IO43) verbinden.
- Den Akku an den `BAT`-Steckplatz am T-HMI anschließen

# Verschrauben

- Das T-HMI in den oberen Teil des Gehäuses einsetzen und mit den vier M2x10-Schrauben verschrauben.
- Die vier Muttern in die Aussparungen des unteren Gehäuses eindrücken.
- Die Batterie mittels Patafix oder doppelseitigem Klebeband (z.B. Tesa Power Strips Small) in die untere Gehäusehälfte kleben.
- Den Luftdrucksensor in die passende Aussparung in der oberen Gehäusehälfte einsetzen.
- Den M5stack Joystick2 in die passende Aussparung in der oberen Gehäusehälfte einsetzen. Dazu muss der Kopf des Joysticks zuerst abgenommen und nach dem Einsetzen wieder aufgesteckt werden.
- Die obere Gehäusehälfte auf die Untere aufsetzen.
- Die vier M3-Schrauben in die Ecken der oberen Gehäusehälfte einsetzen und festschrauben.

Nächster Schritt: [Konfiguration](Configuration_de.md)

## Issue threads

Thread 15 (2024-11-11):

Log executions

Dakkaron, 2024-11-11:
- [ ] Use wifi/NTP to fetch current time (optional, based on whether the user added wifi credentials)
- [ ] Log executions to SD card. An execution includes a timestamp (human readable form), whether the whole execution was finished, number of fails

Closed 2024-12-30.

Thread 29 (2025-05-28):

Spike: Determine whether ESP32-S3 RTC feature can be reasonably used

Dakkaron, 2025-05-28:
Currently, if there's no wifi (and thus no NTP), there's no time for logging purposes.

ESP32-S3 has a built-in RTC feature.

Is this feature usable with the T-HMI board? Can the ESP32-S3 on the T-HMI be powered without poowering other power-draining peripherals on the board?

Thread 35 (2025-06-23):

Game loading screen

Dakkaron, 2025-06-23:
Loading a big game can take a few seconds. Currently it looks like the PEPit has frozen or it didn't react to the user input selecting the game.

Instead, it should show a full-screen loading message.

Closed 2025-07-07.

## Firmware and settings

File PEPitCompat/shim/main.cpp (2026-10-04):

/*
 * PEPitCompat — Main Entry Point (Linux SDL2)
 * 
 * Replaces the Arduino framework's main() on ESP32.
 * Parses CLI arguments, initializes SDL2, then delegates to original setup()/loop().
 * 
 * Usage:
 *   pepit [--data-dir <path>] [--scale <N>] [--fullscreen]
 *         [--low-pressure-key <key>] [--good-pressure-key <key>]
 *         [--help]
 * 
 * Keyboard keys use SDL scancode names (e.g. A, S, LEFT, RIGHT, SPACE).
 * Defaults: low-pressure=A, good-pressure=S.
 */

#include <SDL2/SDL.h>
#include <SDL2/SDL_ttf.h>
#include <csetjmp>
#include <csignal>
#include <cstdint>
#include <getopt.h>
#include <cstring>
#include <cstdio>
#include <cstdlib>
#include <string>

// Shim initialization functions (declared in respective shim files)
extern void initDisplay(SDL_Window** window, SDL_Renderer** renderer);
extern void initSignalHandlers(sigjmp_buf* jumpBuf);
extern void deinitSignalHandlers();

// Global quit flag from arduino.cpp (set by signal handler or vTaskDelay)
extern volatile int32_t g_requestQuit;
extern "C" { void updateSDL(void); }
extern void setTouchDisplayParams(int w, int h, int scale);
extern void setPressureSensorKeys(int lowKey, int goodKey);
extern void initArduino();

// SD_MMC root directory setter (declared in compat/SD_MMC.h)
#include "SD_MMC.h"

// Preferences shim (for touch calibration preloading)
#include "Preferences.h"

// Original source entry points (defined in T-HMI-PEPmonitor/src/main.cpp)
// These are C++ functions, so no extern "C" — let the linker resolve mangled names.
extern void setup();
extern void loop();

// ============================================================
// CLI Argument Parsing
// ============================================================

static const struct option cliOptions[] = {
    {"data-dir",          required_argument, 0, 'd'},
    {"scale",             required_argument, 0, 's'},
    {"fullscreen",        no_argument,       0, 'f'},
    {"low-pressure-key",  required_argument, 0, 'l'},
    {"good-pressure-key", required_argument, 0, 'g'},
    {"help",              no_argument,       0, 'h'},
    {0, 0, 0, 0}
};

static void printUsage(const char* progName) {
    fprintf(stderr, "PEPitCompat — PEPit Linux Compatibility Layer\n");
    fprintf(stderr, "\n");
    fprintf(stderr, "Usage: %s [OPTIONS]\n", progName);
    fprintf(stderr, "\n");
    fprintf(stderr, "Options:\n");
    fprintf(stderr, "  -d, --data-dir <path>       Data directory (default: ./data/)\n");
    fprintf(stderr, "  -s, --scale <N>              Window scale factor (default: 2)\n");
    fprintf(stderr, "  -f, --fullscreen              Start in fullscreen mode\n");
    fprintf(stderr, "  -l, --low-pressure-key <key>  Keyboard key for low pressure (default: A)\n");
    fprintf(stderr, "  -g, --good-pressure-key <key> Keyboard key for good pressure (default: S)\n");
    fprintf(stderr, "  -h, --help                    Show this help message\n");
    fprintf(stderr, "\n");
    fprintf(stderr, "Keyboard keys use SDL scancode names:\n");
    fprintf(stderr, "  A, S, D, W, LEFT, RIGHT, UP, DOWN, SPACE, RETURN, etc.\n");
}

/** Convert SDL scancode name string to integer. Returns -1 on error. */
static int parseScancode(const char* name) {
    if (!name) return -1;
    
    // SDL_GetScancodeFromName takes a string and returns the scancode, or SDL_SCANCODE_UNKNOWN
    SDL_Scancode code = SDL_GetScancodeFromName(name);
    if (code == SDL_SCANCODE_UNKNOWN) {
        // Try parsing as a number directly
        char* endptr;
        long val = strtol(name, &endptr, 10);
        if (*endptr == '\0' && val >= 0 && val < SDL_SCANCODE_UNKNOWN) {
            return (int)val;
        }
        fprintf(stderr, "Warning: unknown scancode '%s', using default\n", name);
        return -1;
    }
    return (int)code;
}

// ============================================================
// SDL2 Initialization
// ============================================================

static bool initSDL(SDL_Window** window, SDL_Renderer** renderer, int scale, bool fullscreen) {
    // Initialize SDL video subsystem
    if (SDL_Init(SDL_INIT_VIDEO) < 0) {
        fprintf(stderr, "Failed to initialize SDL video: %s\n", SDL_GetError());
        return false;
    }
    
    // Initialize SDL_ttf for text rendering
    if (TTF_Init() < 0) {
        fprintf(stderr, "Failed to initialize SDL_ttf: %s\n", TTF_GetError());
        SDL_Quit();
        return false;
    }
    
    // Calculate window dimensions (native display is 320x240)
    int w = 320 * scale;
    int h = 240 * scale;
    
    // Create window
    uint32_t flags = SDL_WINDOW_SHOWN;  // No RESIZABLE — fixed 320x240 display
    if (fullscreen) flags |= SDL_WINDOW_FULLSCREEN_DESKTOP;
    
    *window = SDL_CreateWindow(
        "PEPitCompat",
        SDL_WINDOWPOS_CENTERED,
        SDL_WINDOWPOS_CENTERED,
        w, h,
        flags
    );
    
    if (!*window) {
        fprintf(stderr, "Failed to create SDL window: %s\n", SDL_GetError());
        TTF_Quit();
        SDL_Quit();
        return false;
    }
    
    // Create renderer with software rendering (matches pixel buffer approach)
    *renderer = SDL_CreateRenderer(*window, -1, SDL_RENDERER_SOFTWARE);
    if (!*renderer) {
        fprintf(stderr, "Failed to create SDL renderer: %s\n", SDL_GetError());
        SDL_DestroyWindow(*window);
        TTF_Quit();
        SDL_Quit();
        return false;
    }
    
    return true;
}

// ============================================================
// Main Entry Point
// ============================================================

int main(int argc, char* argv[]) {
    // Capture boot time immediately so millis() returns 0 from program start.
    initArduino();

    // Default configuration
    std::string dataDir = "./data/";
    int windowScale = 2;
    bool fullscreen = false;
    int lowPressureKey = SDL_SCANCODE_A;
    int goodPressureKey = SDL_SCANCODE_S;
    
    // Parse CLI arguments
    int opt;
    while ((opt = getopt_long(argc, argv, "d:s:fl:g:h", cliOptions, nullptr)) != -1) {
        switch (opt) {
            case 'd':
                dataDir = optarg;
                break;
            case 's':
                windowScale = atoi(optarg);
                if (windowScale < 1) windowScale = 1;
                break;
            case 'f':
                fullscreen = true;
                break;
            case 'l': {
                int key = parseScancode(optarg);
                if (key >= 0) lowPressureKey = key;
                break;
            }
            case 'g': {
                int key = parseScancode(optarg);
                if (key >= 0) goodPressureKey = key;
                break;
            }
            case 'h':
                printUsage(argv[0]);
                return 0;
            default:
                printUsage(argv[0]);
                return 1;
        }
    }
    
    // Ensure trailing slash on data directory
    if (!dataDir.empty() && dataDir.back() != '/') {
        dataDir += '/';
    }
    
    // Initialize SDL2 (window + renderer)
    SDL_Window* window = nullptr;
    SDL_Renderer* renderer = nullptr;
    
    if (!initSDL(&window, &renderer, windowScale, fullscreen)) {
        return 1;
    }
    
    // Pass SDL handles to display shim (for texture creation and rendering)
    initDisplay(&window, &renderer);
    
    // Configure touch shim with display dimensions and scale factor
    setTouchDisplayParams(320, 240, windowScale);
    
    // Configure pressure sensor keyboard keys
    setPressureSensorKeys(lowPressureKey, goodPressureKey);
    
    // Configure filesystem root directory and create it if missing
    SD_MMC.setRootDir(dataDir);
    SD_MMC.begin(nullptr, false);

    // Preload spoofed touch calibration so the app skips calibration on first launch
    Preferences::preloadTouchCalibration();

    printf("[PEPitCompat] Data directory: %s\n", dataDir.c_str());
    printf("[PEPitCompat] Window scale: %dx\n", windowScale);
    printf("[PEPitCompat] Pressure keys: low=%s, good=%s\n",
           SDL_GetScancodeName(static_cast<SDL_Scancode>(lowPressureKey)),
           SDL_GetScancodeName(static_cast<SDL_Scancode>(goodPressureKey)));
    printf("[PEPitCompat] Starting application...\n");

    // Set up sigsetjmp BEFORE setup() so signals work even if setup() gets stuck
    sigjmp_buf quitJumpBuf;
    int jumpResult = sigsetjmp(quitJumpBuf, 1);
    if (jumpResult != 0) {
        // We jumped here from the signal handler — quit immediately
        printf("[PEPitCompat] Signal received, exiting...\n");
    }

    // Install signal handlers with jump buffer for immediate escape from tight loops
    initSignalHandlers(&quitJumpBuf);

    // If we jumped here from a signal during setup(), skip the main loop
    if (jumpResult == 0) {
        // Call original setup() — initializes all peripherals and runs UI flow
        setup();

        printf("[PEPitCompat] Entering main loop (press Ctrl+C to exit)\n");

        // Main event loop — pumps SDL events and calls original loop()
        bool running = true;
        while (running) {
            // Check for quit request from signal handler or vTaskDelay/yield
            if (g_requestQuit) {
                running = false;
                break;
            }

            // Pump SDL events each iteration (keeps joystick/sensor keyboard input responsive)
            SDL_Event event;
            while (SDL_PollEvent(&event)) {
                if (event.type == SDL_QUIT) {
                    running = false;
                    break;
                }
                if (event.type == SDL_WINDOWEVENT && event.window.event == SDL_WINDOWEVENT_CLOSE) {
                    running = false;
                    break;
                }
                if (event.type == SDL_KEYDOWN && event.key.keysym.sym == SDLK_ESCAPE) {
                    running = false;
                    break;
                }
            }

            if (!running) break;

            // Call original loop() — handles serial input and game logic
            loop();

            // Ensure display is flushed each frame (fallback if app doesn't call endWrite)
            updateSDL();
        }
    }

cleanup:
    // Cleanup SDL2
    deinitSignalHandlers(); // Disable jump buffer before cleanup
    SDL_DestroyRenderer(renderer);
    SDL_DestroyWindow(window);
    TTF_Quit();
    SDL_Quit();
    
    printf("[PEPitCompat] Exiting cleanly\n");
    return 0;
}

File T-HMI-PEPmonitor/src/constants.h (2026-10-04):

#ifndef __CONSTANTS_H__
#define __CONSTANTS_H__
#include <Arduino.h>

#define VERSION "10.1"

#define LAST_BLOW_SUCCEEDED 0B00000001
#define LAST_BLOW_FAILED    0B00000010
#define NEW_BLOW            0B00000100

#define PRESSURE_BAR_WIDTH 180
#define PRESSURE_BAR_HEIGHT 10
#define PRESSURE_BAR_X 1
#define PRESSURE_BAR_Y 190

#define PRESSURE_SENSOR_DIVISOR 65L
#define PRESSURE_SENSOR_CUTOFF_LIMIT 200
#define PRESSURE_SENSOR_SMOOTHING_NUM_READINGS 10
#define PRESSURE_SENSOR_MAX_SKIPS 10
#define PRESSURE_TARE_TOLERANCE 1

#define PRESSURE_SENSOR_CUMULATIVE_ERROR_FACTOR 16

#define SCREEN_BRIGHTNESS_STEPS 16
#define SCREEN_ROTATION 3
#define SCREEN_WIDTH 320
#define SCREEN_HEIGHT 240

#define M5STACK_JOYSTICK2_POWER_PIN 43

#define HX7711_DATA_PIN 17
#define HX7711_CLOCK_PIN 18

#define SIMULATE_BLOWS_SHORT_BLOW_DURATION 1000
#define SIMULATE_BLOWS_PAUSE_DURATION 5000

#define BATTERY_LOW_WARNING_VOLTAGE 3400
#define BATTERY_LOW_SHUTDOWN_VOLTAGE 3300

#define SENSOR_MODE_PEPS 1
#define SENSOR_MODE_TRAMPOLINE 2

#define PROGRESS_MENU_SELECTION_ID 32767
#define SYSTEM_UPDATE_SELECTION_ID 32766
#define EXECUTION_LIST_SELECTION_ID 32765

#define PROFILE_TASK_TYPE_SHORTBLOWS 1
#define PROFILE_TASK_TYPE_LONGBLOWS 2
#define PROFILE_TASK_TYPE_EQUALBLOWS 3
#define PROFILE_TASK_TYPE_TRAMPOLINE 4
#define PROFILE_TASK_TYPE_INHALATION 5
#define PROFILE_TASK_TYPE_INHALATIONPEP 6

#define INHALATION_TASK_WARN_TIMEOUT 10000L
#define INHALATION_TASK_END_TIMEOUT 15000L

#define MAX_WIFI_NETWORKS 3
#define FILE_DOWNLOAD_CHUNK_SIZE 1024*10
#define FILE_DOWNLOAD_TO_STRING_MAX_SIZE 1024
#define FIRMWARE_RELEASE_PATH_URL "https://raw.githubusercontent.com/Dakkaron/T-HMI-PEPmonitor/refs/heads/main/path_to_latest_release"
#define LAST_RELEASE_URL_FILE_PATH "/lastReleaseUrl.txt"
#define FIRMWARE_FILE_NAME "firmware.bin"
#define SDCARD_CONTENT_FILE_NAME "SDCardContent.tar"

#define GAME_SELECTION_POWEROFF_TIMEOUT 3L*60L*1000L // Power off device if it spends >3 minutes on game selection screen
#define WIN_SCREEN_TIMEOUT 3L*60L*1000L
#define SHOW_SYSTEM_UPDATE_ON_WINSCREEN_TIMEOUT 3L*1000L

#define MANOMETER_WINSCREEN_PATH "/gfx/manometerWinscreen.bmp"

#define REQUIRED_TASK_TYPE_SHORTBLOWS       0b00000001
#define REQUIRED_TASK_TYPE_LONGBLOWS        0b00000010
#define REQUIRED_TASK_TYPE_EQUALBLOWS       0b00000100
#define REQUIRED_TASK_TYPE_TRAMPOLINE       0b00001000
#define REQUIRED_TASK_TYPE_INHALATION       0b00010000
#define REQUIRED_TASK_TYPE_INHALATIONPEP    0b00100000
#define REQUIRED_TASK_TYPE_PROGRESSION_MENU 0b01000000

#define COLOR_BUTTON_PRIMARY       0x001F
#define COLOR_BUTTON_PRIMARY_FRAME 0x94b2
#define COLOR_BUTTON_PRIMARY_TEXT  0xFFFF
#define COLOR_BUTTON_SELECTABLE    TFT_YELLOW

struct GameConfig {
  String name;
  String templateName;
  String prefsNamespace;
  String pepShortScriptPath;
  String pepLongScriptPath;
  String pepEqualScriptPath;
  String inhalationPepScriptPath;
  String inhalationScriptPath;
  String trampolineScriptPath;
  String progressionMenuScriptPath;
  String winScreenScriptPath;
};

struct ProfileData {
  String name = "";
  String imagePath = "";
  uint8_t cycles = 0;
  uint8_t tasks = 0;
  uint8_t taskType[10];
  uint8_t taskRepetitions[10];
  String taskChangeImagePath[10];
  String taskChangeMessage[10];
  uint32_t taskTime[10];
  uint32_t taskMinStrength[10];
  bool taskNegativeStrength[10];
  uint32_t taskTargetStrength[10];
  uint32_t taskTime2[10];
  uint32_t taskMinStrength2[10];
  bool taskNegativeStrength2[10];
  uint32_t taskTargetStrength2[10];
};


struct BlowData {
  bool currentlyBlowing = false;
  unsigned long ms = 0;
  unsigned long blowStartMs = 0;
  unsigned long blowEndMs = 0;
  unsigned long targetDurationMs = 0;
  unsigned long totalTimeSpentBreathing = 0;
  unsigned long taskStartMs;
  int32_t breathingScore = 0;
  uint8_t cycleNumber = 0;
  uint8_t totalCycleNumber = 0;
  uint8_t taskNumber = 0;
  uint8_t totalTaskNumber = 0;
  uint8_t blowCount = 0;
  uint8_t totalBlowCount = 0;
  float pressure = 0;
  bool negativePressure = false;
  int32_t peakPressure = 0;
  int32_t minPressure = 0;
  int32_t targetPressure = 0;
  uint32_t cumulativeError = 0;
  uint32_t successes = 0;
  uint32_t fails = 0;
  uint32_t taskType;
  uint8_t lastBlowStatus = 0;
  uint32_t totalLongBlowRepetitions = 0;
  uint32_t totalEqualBlowRepetitions = 0;
  uint32_t totalShortBlowRepetitions = 0;
};


struct JumpData {
  unsigned long ms = 0;
  unsigned long startMs = 0;
  int32_t msLeft = 0;
  uint8_t cycleNumber = 0;
  uint8_t totalCycleNumber = 0;
  uint8_t taskNumber = 0;
  uint8_t totalTaskNumber = 0;
  uint16_t jumpCount = 0;
  uint16_t bonusJumpCount = 0;
  bool currentlyJumping = false;
  int32_t totalTime = 0;
  uint16_t misses = 0;
  uint16_t highscore = 0;
  bool newHighscore = false;
};

#endif /* __CONSTANTS_H__ */

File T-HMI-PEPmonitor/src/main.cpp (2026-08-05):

#include <Arduino.h>
#define CONFIG_SPIRAM_SUPPORT 1

#include "systemconfig.h"
#include "constants.h"

#include <SD_MMC.h>
#include <FS.h>
#include <SPI.h>
#include <SD.h>
#include <OneButton.h>
#include "esp_log.h"
#include "esp_err.h"
#include "driver/ledc.h"
#include "esp_pm.h"

#include "hardware/gfxHandler.hpp"
#include "hardware/pressuresensor.h"
#include "hardware/touchHandler.h"
#include "hardware/wifiHandler.h"
#include "hardware/sdHandler.h"
#include "games/games.h"
#include "hardware/serialHandler.h"
#include "hardware/powerHandler.h"
#include "physioProtocolHandler.h"
#include "updateHandler.h"
#include "hardware/bluetoothHandler.h"
#include "systemStateHandler.h"
#include "hardware/joystickHandler.h"

#define LEDC_TIMER              LEDC_TIMER_0
#define LEDC_MODE               LEDC_LOW_SPEED_MODE
#define LEDC_OUTPUT_IO          BK_LIGHT_PIN // Define the output GPIO
#define LEDC_CHANNEL            LEDC_CHANNEL_0
#define LEDC_DUTY_RES           LEDC_TIMER_13_BIT // Set duty resolution to 13 bits
#define LEDC_DUTY               (4096) // Set duty to 50%. (2 ** 13) * 50% = 4096
#if CONFIG_PM_ENABLE
#define LEDC_CLK_SRC            LEDC_USE_RC_FAST_CLK // choose a clock source that can maintain during light sleep
#define LEDC_FREQUENCY          (400) // Frequency in Hertz. Set frequency at 400 Hz
#else
#define LEDC_CLK_SRC            LEDC_AUTO_CLK
#define LEDC_FREQUENCY          (4000) // Frequency in Hertz. Set frequency at 4 kHz
#endif

static void example_ledc_init(void) {
    // Prepare and then apply the LEDC PWM timer configuration
    ledc_timer_config_t ledc_timer = {
        .speed_mode       = LEDC_MODE,
        .duty_resolution  = LEDC_DUTY_RES,
        .timer_num        = LEDC_TIMER,
        .freq_hz          = LEDC_FREQUENCY,  // Set output frequency at 4 kHz
        .clk_cfg          = LEDC_CLK_SRC,
    };
    ESP_ERROR_CHECK(ledc_timer_config(&ledc_timer));

    // Prepare and then apply the LEDC PWM channel configuration
    ledc_channel_config_t ledc_channel = {
        .gpio_num       = LEDC_OUTPUT_IO,
        .speed_mode     = LEDC_MODE,
        .channel        = LEDC_CHANNEL,
        .timer_sel      = LEDC_TIMER,
        .duty           = 0, // Set duty to 0%
        .hpoint         = 0,
#if CONFIG_PM_ENABLE
        .sleep_mode     = LEDC_SLEEP_MODE_KEEP_ALIVE,
#endif
    };
    ESP_ERROR_CHECK(ledc_channel_config(&ledc_channel));
}

/*
 * value: 0-8191
 */
void setBrightness(uint32_t value) {
  ESP_ERROR_CHECK(ledc_set_duty(LEDC_MODE, LEDC_CHANNEL, value));
  // Update duty to apply the new value
  ESP_ERROR_CHECK(ledc_update_duty(LEDC_MODE, LEDC_CHANNEL));
  //analogWrite(BK_LIGHT_PIN, value);
  /*if (value == 255) {
    digitalWrite(BK_LIGHT_PIN, 1);
  } else {
    analogWrite(BK_LIGHT_PIN, _max(value, 10));
  }*/
}

void setup() {
  esp_log_level_set("wifi", ESP_LOG_WARN);
  pinMode(PWR_ON_PIN, OUTPUT);
  digitalWrite(PWR_ON_PIN, HIGH);
  pinMode(BK_LIGHT_PIN, OUTPUT);
  digitalWrite(BK_LIGHT_PIN, LOW);
  example_ledc_init();
  setBrightness(0);

  pinMode(M5STACK_JOYSTICK2_POWER_PIN, OUTPUT); // Activate joystick power
  digitalWrite(M5STACK_JOYSTICK2_POWER_PIN, HIGH);

  gpio_deep_sleep_hold_dis();
  gpio_hold_dis(GPIO_NUM_14);
  gpio_deep_sleep_hold_en();
  gpio_hold_en(GPIO_NUM_14); // Make sure PWR_ON_PIN stays active even in deep sleep

  esp_log_level_set("gpio", ESP_LOG_ERROR);

  Serial.print("PEPit Version '");
  Serial.print(VERSION);
  Serial.println("'");
  Serial.print("Initializing peripherals....");

  Serial.setRxBufferSize(10240);
  Serial.setTxBufferSize(1024);
  Serial.begin(115200);

  pinMode(PWR_EN_PIN, OUTPUT);
  digitalWrite(PWR_EN_PIN, HIGH);

  getSystemUpdateAvailableStatus(); // Trigger connecting to Wifi
  tft.init();
  tft.setRotation(SCREEN_ROTATION);
  tft.setSwapBytes(false);
  tft.fillScreen(TFT_BLACK);

  initGfxHandler();
  tft.setTextSize(2);
  if (!isSkipSplashScreen()) {
    tft.drawString("Nicht", 10, 10);
    tft.drawString("blasen!", 10, 25);
  }
  String errorMessage;
  initPressureSensor(&errorMessage);
  buttonPwr.attachClick(power_off);
  buttonPwr.attachLongPressStop(power_off);
  buttonUsr.attachLongPressStop(runTouchCalibration);
  initTouch();

  checkFailWithMessage(errorMessage);

  randomSeed(analogRead(0));
  
  initSD(&errorMessage);
  checkFailWithMessage(errorMessage);
  
  if (!isSkipSplashScreen()) {
    loadBmp(&spr, "/gfx/splash.bmp");
    spr.pushSpriteFast(0,0);
  }
  checkForPrefsReset();
  initSystemConfig(&errorMessage);
  checkFailWithMessage(errorMessage);
  configTime(systemConfig.timezoneOffset, 0, "pool.ntp.org", "time.nist.gov");

  uint8_t defaultTextDatum = tft.getTextDatum();
  tft.setTextColor(TFT_BLACK);
  tft.setTextDatum(TR_DATUM);
  if (!isSkipSplashScreen()) {
    tft.drawString("Version "+String(VERSION), 320, 2);
    tft.setTextDatum(defaultTextDatum);
    Serial.println(F("done"));
    delay(1000);
  }
  
  Serial.print("PEPit Version '");
  Serial.print(VERSION);
  Serial.println("' initialized");

  checkForAndRunUpdateFromSD(&errorMessage);
  checkFailWithMessage(errorMessage);

  Serial.print("Joystick present: ");
  Serial.println(isJoystickPresent());

  Serial.println("Connecting to trampoline...");
  connectToTrampoline(false);
  Serial.println("MARKER DONE");
  setSystemState(STATE_PROFILE_SELECTION);
  uint32_t requiredTaskTypes = runProfileSelection();
  if ((requiredTaskTypes & REQUIRED_TASK_TYPE_TRAMPOLINE) == 0) {
    Serial.print("Disabling Bluetooth...");
    disableBluetooth();
    Serial.println("done");
  }
  setSystemState(STATE_GAME_SELECTION);
  if (!systemConfig.manometerMode) {
    runGameSelection(requiredTaskTypes);
  }
  setSystemState(STATE_GAME_RUNNING);
  displayPhysioRotateScreen();
}

void loop() {
  handleSerial();
  handlePhysioTask();
  /*Serial.print("Free heap: ");
  Serial.println(ESP.getFreeHeap());*/
}

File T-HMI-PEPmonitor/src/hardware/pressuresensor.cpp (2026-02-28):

#include "hardware/pressuresensor.h"
#include <Adafruit_HX711.h>
#include "systemconfig.h"

static Adafruit_HX711 hx711 = Adafruit_HX711(HX7711_DATA_PIN, HX7711_CLOCK_PIN);

void initPressureSensor(String* errorMessage) {
  hx711.begin();
  Serial.print("Tareing air pressure sensor....");
  for (uint32_t i=0; i<=10000000; i++) {
    if (!hx711.isBusy()) {
      break;
    }
    if (i==10000000) {
      errorMessage->concat("Luftdruck-Sensor nicht gefunden!\n");
      return;
    }
  }
  for (uint8_t t=0; t<3; t++) {
    hx711.tareA(hx711.readChannelRaw(CHAN_A_GAIN_64));
    hx711.tareA(hx711.readChannelRaw(CHAN_A_GAIN_64));
  }
  Serial.print("done");

}

void powerDownPressureSensor(bool down) {
  hx711.powerDown(down);
}

void readPressure(BlowData* blowData) {
  static float readings[PRESSURE_SENSOR_SMOOTHING_NUM_READINGS];
  static uint8_t readIndex = 0;
  static float total = 0;
  static uint8_t skips = 0;
  static float tare = 0;
  if (blowData->ms + 4999 < millis()) {
    for (int i=0;i<PRESSURE_SENSOR_SMOOTHING_NUM_READINGS;i++) {
      readings[i] = 0;
    }
  }
  if (systemConfig.simulateBlows) {
    uint32_t blowDuration = blowData->ms - blowData->blowStartMs;
    uint8_t isBlowing = (blowDuration) < (blowData->targetDurationMs+100) ||
                        (blowDuration) > (blowData->targetDurationMs+100+SIMULATE_BLOWS_PAUSE_DURATION);
    blowData->pressure = isBlowing ? 98 : 1; 
  } else {
    if (hx711.isBusy()) {
      return;
    }
    float sensorValue = (hx711.readChannel(CHAN_A_GAIN_64) / (PRESSURE_SENSOR_DIVISOR * blowData->targetPressure));
    if (systemConfig.debugLogBlowPressure) {
      Serial.print(F("Channel A (Gain 64): "));
      Serial.print(sensorValue);
      Serial.print(F(" / "));
    }
    if (blowData->negativePressure) {
      sensorValue = -sensorValue;
    }
    if (sensorValue >= -PRESSURE_SENSOR_CUTOFF_LIMIT && sensorValue <= PRESSURE_SENSOR_CUTOFF_LIMIT) {
      skips = 0;
      total = total - readings[readIndex];
      readings[readIndex] = sensorValue;
      total = total + readings[readIndex];
      readIndex = (readIndex + 1) % PRESSURE_SENSOR_SMOOTHING_NUM_READINGS;
      blowData->pressure = total / PRESSURE_SENSOR_SMOOTHING_NUM_READINGS;
      if (blowData->pressure < tare) {
        tare -= 0.001;
      } else if (blowData->pressure > tare && blowData->pressure <= tare + PRESSURE_TARE_TOLERANCE) {
        tare += 0.001;
      } else if (blowData->pressure > tare + PRESSURE_TARE_TOLERANCE) {
        float diff = blowData->pressure - tare;
        tare += 0.001 / (diff * diff);
      }
      blowData->pressure = _max(0, blowData->pressure-tare);
      if ((blowData->ms - blowData->blowStartMs) < blowData->targetDurationMs) {
        blowData->cumulativeError = abs(((int32_t)blowData->pressure - 100)) + ((blowData->cumulativeError * (PRESSURE_SENSOR_CUMULATIVE_ERROR_FACTOR-1)) / PRESSURE_SENSOR_CUMULATIVE_ERROR_FACTOR);
      }
    } else {
      skips++;
      if (skips > 10) {
        skips--;
        total = total - readings[readIndex];
        readings[readIndex] = 0;
        total = total + readings[readIndex];
        readIndex = (readIndex + 1) % PRESSURE_SENSOR_SMOOTHING_NUM_READINGS;
        blowData->pressure = total / PRESSURE_SENSOR_SMOOTHING_NUM_READINGS;
        if ((blowData->ms - blowData->blowStartMs) < blowData->targetDurationMs) {
          blowData->cumulativeError = abs(((int32_t)blowData->pressure - 100)) + ((blowData->cumulativeError * (PRESSURE_SENSOR_CUMULATIVE_ERROR_FACTOR-1)) / PRESSURE_SENSOR_CUMULATIVE_ERROR_FACTOR);
        }
      }
    }
  }
  if (systemConfig.debugLogBlowPressure) {
    Serial.println(blowData->pressure);
  }
}

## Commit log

2025-06-22 Fixed bug with erroneous double updates; update check is now based on currently installed version instead of saved last update URL
2025-06-24 Added stage 4 to miner game; fixed structure generation in miner trampoline game
2025-06-25 Added miner game stage 7 data;refactoring progression menu
2025-07-19 Autobalancing 2-threaded rendering for mode7 background
2025-07-26 Fixed handling of empty executionsLog; added "Back" button to executionsLog
    [physioProtocolHandler.cpp]
2025-07-26 Increased default pressures for PEP S and RC Cornet, decreased pressure and duration for inhalation
2025-07-29 Report missing pressure sensor
    [main.cpp, pressuresensor.cpp]
2025-07-31 Added task type inhalationPep and renamed task types equalBlow, longBlow and shortBlow to pepEqual, pepLong and pepShort.
    [physioProtocolHandler.cpp]
2025-08-04 Added physio device configurations for documentation
2025-08-04 Added Devices_de.md
2025-08-04 Fixed handling multiple configured wifi networks
    [main.cpp]
2025-08-08 Made file upload more fault resistant.
2025-08-10 Fixed showing version on boot screen
    [main.cpp]
2025-08-19 Moved touch calibration prefs from touch->calib to system->touch
2025-08-19 Added option to dump and reset prefs via serial
    [pressuresensor.cpp]
2025-09-16 Initial TOF+BLE based trampoline sensor firmware
2025-09-16 Initial bluetooth trampoline sensor support
2025-10-04 "silent" reboot without splash screen on internal and USB reset
    [main.cpp]
2025-10-17 Fix small display glitch on win screen
    [physioProtocolHandler.cpp]
2025-12-26 Fixed bug where old content would remain in back buffer before win screen
    [physioProtocolHandler.cpp]
2025-12-28 Added systemStateHandler that informs all components about the current execution phase. Also made sure that system update check doesn't run after game has started.
    [main.cpp]
2025-12-28 Added buttonUp.bmp and buttonDown.bmp to horseracing game
2026-01-20 unified handling of button updates and system stat rendering
2026-01-20 Moved button listeners to init before first checkFailWithMessage()
2026-01-20 checkFailWithMessage() now correctly handles power button
2026-01-24 Updated 3D print files to version 4.1
    [T_HMI_PEP_case_v3.3.blend, T_HMI_PEP_case_v3.3_bottom.stl, T_HMI_PEP_case_v3.3_bottom_hexnuts.stl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]
2026-01-28 Bugfix horserace: track now doesn't wobble if there's a jump obstacle
2026-02-08 Closes #27, added auto-taring pressure sensor to counteract sensor drift
    [constants.h, pressuresensor.cpp]
2026-02-08 Fixed displaying status text between game and winscreen, improved logging
    [physioProtocolHandler.cpp]
2026-02-08 Case v4.2
    [T_HMI_PEP_case_v4.1_battery_lid.stl, T_HMI_PEP_case_v4.1_bottom_with_hexnuts.stl, T_HMI_PEP_case_v4.1_bottom_with_squarenuts.stl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]
2026-02-11 Add German implementation details for pressure sensor
2026-02-19 Added workaround for erroneous joystick readings; disabled joystick LED; fixed setJoystickRGB()
2026-02-25 Fixed main menu flickering on boot
    [main.cpp]
2026-02-28 Deep sleep instead of poweroff; deep-sleep-reset button on winscreen
2026-03-01 Fixed deepSleepReset() when USB is powered
2026-06-16 Fixed byte swapping madness
    [main.cpp]
2026-07-22 Fixed "failed to wake up" bug
    [main.cpp]
2026-07-22 Added functionality to restart from charging display
2026-07-31 Sped up compillation by switching from lib_ldf_mode chain+ to chain.
2026-08-05 Screen brightness pwm control
2026-08-05 Smoothing battery voltage read-out
2026-08-05 Fixed graphical bug for reboot button
    [physioProtocolHandler.cpp]
2026-08-30 filemanager.py: added clearprefs, backupprefs, restoreprefs, printprefs, hard-reset, fixed dl, dlr and reset
2026-09-12 Added String.replace() and fixed _min() and _max() for pepit_compat shims
    [Arduino.h]
2026-09-12 Fixed missing variable initializations
    [constants.h, physioProtocolHandler.cpp]
2026-09-12 Added the ability to draw the character "€" with DrawString() and Print()
2026-09-12 On all games: changed "$" to "€"
2026-09-13 Fixed "€" handling in PrintLn(); updated Documentation
2026-10-04 Added Joystick to assembly documentation
2026-10-21 Added hidden self-test "game" (press battery icon 5x during game selection to open)
2026-10-22 Improved battery voltage reading; Added battery charging symbol; fixed graphical glitch during update
2026-10-28 Blanking frame buffer before update screen to avoid graphical glitch
2026-10-29 Add native unit tests for the firmware + fix INI key prefix matching
    Test infrastructure (PEPitCompat — builds the unmodified firmware source
    on Linux):
    - Fix Preferences shim signatures (putBytes/getBytes) to match the
    current arduino-esp32 core, which had broken the native build
    - Extract shared SDL/TTF init into shim/appinit.{h,cpp} (app + tests)
    - CMake: pepit_core static library shared by the app and a new
    pepit_tests target; CTest integration
    - Vendor Catch2 v3.5.4 (Boost License 1.0) for the test binary
    - 37 test cases / 136 assertions covering the INI parser and
    system/profile/game config parsing, run headless (SDL dummy driver)
    - GitHub Actions workflow running the suite on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
2026-10-30 Add pressure, log, game, time and matrix tests + test-safe clock shim
    Tests (PEPitCompat/tests, all headless):
    - test_pressure_sensor: moving average, cutoff/skip, negative clamp,
    cumulative error, simulate mode, idle-timeout quirk (must stay last —
    it injects a permanent phantom into the static running total)
    - test_execution_log: logExecutionToSD writes + the app's own readers
    (readFileToNewPSBuffer, readFileLineToString) with per-field checks
    of date, time, successes, fails, duration
    - test_game_selection: template shortcut, per-script task support,
    hidden games, getNumberOfGames/getGamePath
    - test_time_handling: format, faked-time round-trip, keeps-running,
    host-clock-untou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
2026-11-01 Trim test and shim comments to the essentials
    Only comments the code cannot tell are kept: shim rationale (host clock
    never touched, TZ=UTC baseline, FILE_APPEND create semantics, test-only
    hooks), quirk/REGRESSION context, and non-obvious invariants (static
    filter state ordering, matrix conventions, Approx margin). Restated
    explanations, section banners and one unused helper removed. No logic
    changes; suite unchanged.
2026-11-01 Add missing esp_adc shim headers for the host build
    powerHandler.cpp includes esp_adc/{adc_oneshot,adc_cali,adc_cali_scheme}.h,
    but these compat stubs were never committed, so the CI build fails with
    'fatal error: esp_adc/adc_oneshot.h: No such file or directory'.
2026-11-01 Align PEPitCompat README with the CI fix
    - Use the libsdl2-ttf-dev package name (valid on Ubuntu 20.04 through
    26.04; the old libsdl2-ttf-2.0-dev no longer exists on current releases)
    - Document the native unit test harness (ctest / pepit_tests)
2026-11-01 Fix the pinned quirks in matrix, INI, and pressure code
    - invertM: return bool; singular matrix (det ~ 0) reports false instead
    of silently leaving the output unmodified.
    - normalizeVector: output = normalized input (was scaling the output in
    place, so a zeroed output stayed zero).
    - getIniSection: keep the final line of a file that lacks a trailing
    newline (was silently dropped).
    - File::available() shim: report exact remaining byte count like the
    arduino-esp32 core (feof() let while(available()) loops read one
    phantom 0 byte past EOF).
    - readPressure: the idle timeout resets the running total along with the
    window (was a permanent phantom in every later average).
    - stringIsTrue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
